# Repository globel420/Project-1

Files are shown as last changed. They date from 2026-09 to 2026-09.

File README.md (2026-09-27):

# MAKR 100 — Project 1

## Binary Counter and Logical Operators

**Harry Bartos · MAKR 100 · Fall 2026**

I combined Option A and Option B into one Arduino Uno project. The same set of LEDs displays a binary count in one mode and logical operators in the other. A short press counts; a five-second hold switches modes. The circuit is housed in a custom 3D-printed enclosure.

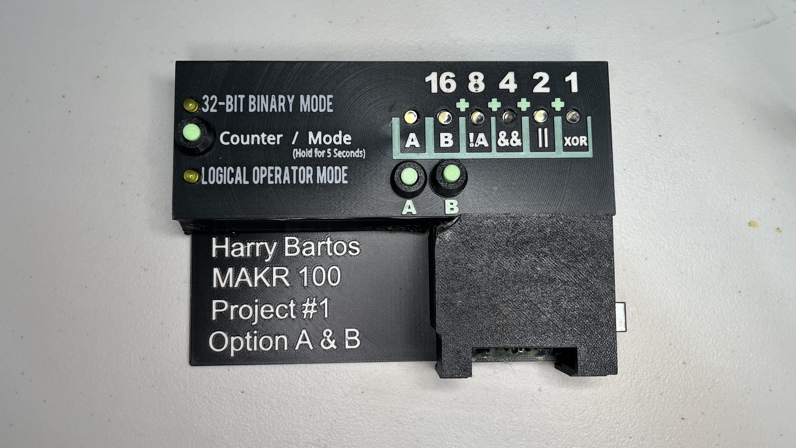
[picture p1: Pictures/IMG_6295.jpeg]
Project 1 enclosure with labeled LEDs, Counter/Mode button, and A/B buttons


## What it does

- **Project A — Binary counter:** counts from **0 to 31** using five LEDs with weights **16, 8, 4, 2, 1**. The next count after 31 returns to 0. Five bits give 32 possible values.
- **Project B — Logical operators:** buttons A and B control six outputs: **A**, **B**, **NOT A**, **AND**, **OR**, and **XOR**.
- **Shared controls:** hold Counter/Mode for five seconds to switch projects. Two indicator LEDs show the active mode. The count is preserved when switching modes and resets to zero when the Arduino restarts.
- **Serial output:** displays the decimal count or logic results at **9600 baud**.

### Controls

| Control | Action |
| --- | --- |
| Counter/Mode: short press and release | Add one in Project A; the increment happens on release |
| Counter/Mode: hold for five seconds | Switch between Projects A and B |
| Button A / Button B | Set the two inputs in Project B |

The buttons connect to ground and use `INPUT_PULLUP`: pressed reads `LOW`, released reads `HIGH`. The Mode button has a 50 ms debounce interval, and one long hold changes modes only once.

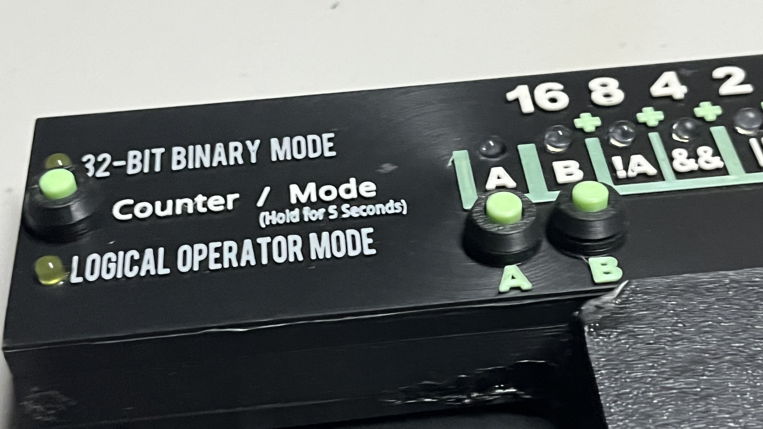
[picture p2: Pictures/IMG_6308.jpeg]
Close-up of the mode indicators, printed labels, and A/B controls


## Demo video

**Coming soon — the finished demonstration video has not been recorded yet.**

The files in [Pictures](Pictures/) and [Video](Video/) include photos, saved camera clips, animation drafts, and narration material. They are working materials for the project, not a finished demonstration video.

## Hardware and wiring

- Arduino Uno R3 and a USB cable
- Three push buttons
- Six shared data LEDs and two mode indicator LEDs
- Eight 220 Ω resistors, one for each LED
- Prototyping board, wire, and the printed enclosure

The full quantities are in [List Of Materials.xlsx](List%20Of%20Materials.xlsx).

| Uno pin | Project A: binary counter | Project B: logical operators |
| --- | --- | --- |
| D2 | Counter/Mode button | Mode button |
| D3 | Button A, unused in this mode | Button A input |
| D4 | Button B, unused in this mode | Button B input |
| D5 | Project A indicator on | Project A indicator off |
| D6 | Project B indicator off | Project B indicator on |
| D7 | Off | A |
| D8 | 16s bit | B |
| D9 | 8s bit | NOT A |
| D10 | 4s bit | A AND B |
| D11 | 2s bit | A OR B |
| D12 | 1s bit | XOR: exactly one input pressed |

### Circuit layout

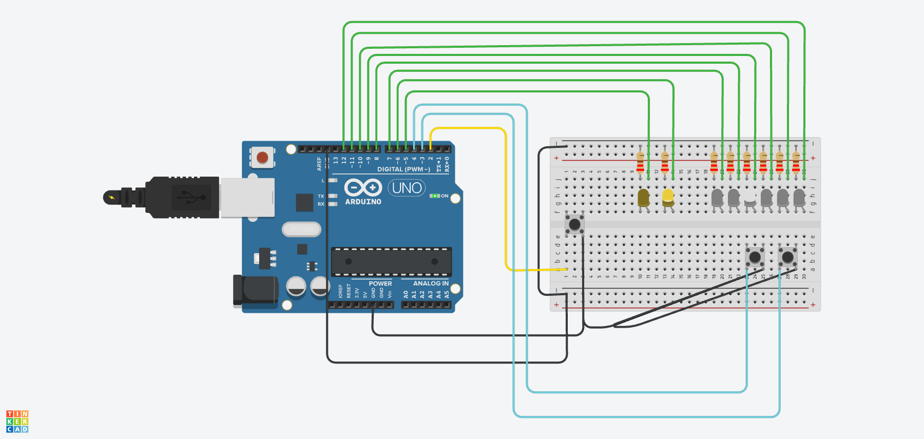
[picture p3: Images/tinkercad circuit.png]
Tinkercad circuit showing the Arduino Uno, eight LEDs with resistors, and three buttons


See the [wiring diagram PDF](Images/Wire%20Diagram.pdf) for another view. The current pin assignments and behavior are defined in [Program.cpp](Program/Program.cpp).

### Logic results

Here, **1 means pressed/on** and **0 means released/off**.

| A | B | NOT A | AND | OR | XOR |
| --- | --- | --- | --- | --- | --- |
| 0 | 0 | 1 | 0 | 0 | 0 |
| 1 | 0 | 0 | 0 | 1 | 1 |
| 0 | 1 | 1 | 0 | 1 | 1 |
| 1 | 1 | 0 | 1 | 1 | 0 |

The program uses the full XOR expression: `(A && !B) || (!A && B)`.

## Build and upload

The active source is **[Program/Program.cpp](Program/Program.cpp)**. [platformio.ini](platformio.ini) selects the Arduino Uno, the Arduino framework, and the `Program` source folder.

1. Open this repository folder in **VS Code with PlatformIO**.
2. Connect the Uno by USB.
3. Select **PlatformIO → Project Tasks → uno → General → Build**.
4. Select **Upload** to compile and write the firmware to the board.
5. Open **Monitor** at **9600 baud**.

With PlatformIO Core available in your terminal, run these commands from the repository root:

```sh
pio run -e uno
pio run -e uno --target upload
pio device monitor --baud 9600
```

The `.cpp` conversion added function declarations without changing program logic. Both versions built successfully, and the resulting firmware files were byte-for-byte identical: **3,422 bytes of flash and 409 bytes of RAM**. The original `.ino` and comparison record are preserved in [Backups](Backups/).

Keep the backup sketch outside `Program/` so PlatformIO compiles only the active source.

## Project files

| Location | Contents |
| --- | --- |
| [Program](Program/) | Main combined counter/logic program |
| [Binary_Counter_Only](Binary_Counter_Only/) | Standalone counter sketch and its flowcharts |
| [Flowcharts](Flowcharts/) | Main program, button, counter, and logic flowcharts |
| [Images](Images/) | Circuit diagram and additional flowchart images |
| [Pictures](Pictures/) | Build photos and saved camera clips |
| [print files](print%20files/) | Bambu Studio 3MF project and enclosure/button STL files |
| [Report](Report/) | Word and Markdown project report, plus inventory notes |
| [Video](Video/) | Animation sources, draft exports, scripts, and archived revisions |
| [Diagnostics](Diagnostics/) | Mode-button troubleshooting notes and diagnostic sketch |
| [Backups](Backups/) | Original sketch and conversion records |
| [Instructions.pdf](Instructions.pdf) | Assignment instructions |

The report and older diagrams may refer to `Program.ino`; the active PlatformIO source is now `Program.cpp`.

### Downloading the media

Video files are stored with **Git LFS**. To get the full media files when cloning:

```sh
git lfs install
git clone https://github.com/globel420/Project-1.git
cd Project-1
git lfs pull
```

Build output, macOS metadata, and local automation caches are excluded from Git.

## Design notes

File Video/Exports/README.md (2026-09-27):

# Project 1 animation exports

Silent 1080p animation prepared for your own spoken narration.

| Video | Length | Contents |
|---|---:|---|
| Project_1_LED_Animation.mp4 | 3:30 | Complete corrected animation |
| Binary_Counter_Animation.mp4 | 1:50 | LED values, 13, main functions, actual shift/mask operations, rollover |
| Logic_Operators_Animation.mp4 | 1:40 | Button states, NOT A, AND, OR, XOR, all combinations, repeat loop |

All three are H.264 MP4, 1920 × 1080, 24 frames per second, with no audio track.

The complete animation follows `../Animation_Spoken_Script.md` and `../Animation_Narration.srt`. The logic-only video starts at 1:50 in the full animation, so its local time begins 110 seconds earlier than the full-script timestamps.

Use the animation full frame for the explanation or place it beside your recorded hardware footage. The animation is an illustration of the sketch, not a live Arduino connection.

Mint means ON / 1. Gray means OFF / 0. Amber highlights the position or rule currently being explained; the highlight itself does not change the LED result.

## Corrected binary section

- The LED graphics run left to right as 1, 2, 4, 8, 16, following array indices 0 through 4 and pins D12 through D8.
- Written binary used in calculations retains its highest-value position on the left. It is labeled separately from the LED layout.
- The animation shows the actual Arduino bitRead operation: `(value >> bit) & 0x01`. It shifts right, masks all but the rightmost bit, then writes the 0 or 1 result to the pin.
- The comparison shows count 2 returning 1 for the 2s LED, while count 13 returns 0 for that same LED.
- The full and binary videos replace the prior explanation. The logic-only MP4 is preserved byte for byte.

QA: all scene layouts inspected; input, shifted, and masked binary values and pin mappings checked against the narration contract; all three final videos fully decoded without errors. QA_Stills includes frames extracted from the completed MP4, including the shift/mask comparison, the 2s bit, and XOR with both buttons pressed. Exact stream and duration checks are in render_validation.json.

Prior exports and superseded QA are preserved under `../render_work/archive_before_shift_mask_revision/`.

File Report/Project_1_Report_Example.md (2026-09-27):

# Project 1 Report

## Binary Counter and Logical Operators

Harry Bartos  
MAKR 100 Introduction to Microcontrollers and Physical Computing  
Instructor Nicole Shuman  
Fall 2026

### What I completed

For Project 1, I completed both Option A, the binary counter, and Option B, the logical operators project. I combined them into one Arduino build with a shared set of LEDs and a button that switches between the two modes. I also 3D printed a shell for the project and moved the circuit from the breadboard onto a soldered prototyping board.

I decided to do both because I have a passion for making things, and I had the opportunity. That was a big part of it. I know I probably won't have as many chances to do extra work like this later in the semester, so I wanted to take advantage of the time and equipment I had available. Combining the two options gave me a little more to figure out, especially because the same LEDs have different jobs depending on which project is running.

### Materials I used

My materials list records the following parts and printing material.

| Component or material | Quantity | Use |
| --- | --- | --- |
| Arduino Uno R3 | 1 | Runs both project modes |
| Push buttons | 3 | Counter/Mode button and inputs A and B |
| Data LEDs | 6 | Shared binary and logical output display |
| Yellow mode indicator LEDs | 2 | Show which project is active |
| 220 ohm resistors | 8 | One in series with each LED |
| Solderable prototyping board | 1 | Holds the soldered circuit |
| 22 gauge stranded copper wire | 40 inches | Circuit connections |
| Black PLA | 151 grams | Printed project parts |
| Green glow PLA | 34 grams | Printed project parts |
| White PLA | 4 grams | Printed project parts |

I also used a solderless breadboard during the earlier part of the build. Reproducing the project requires a suitable USB cable and a computer with the Arduino IDE to upload the sketch. The enclosure parts are saved as STL files, and the Bambu Studio project is included as a 3MF file.

### Designing in Tinkercad and printing the shell

I did the design work in Tinkercad. I used the circuit simulator to work on the electronics, and I also designed the 3D parts there. The 3D design probably took me the most time out of the whole project.

I was able to print the project's shell early on, and there is a personal reason that part of the project meant a lot to me. Falcons Care at Folsom Lake College helped me with temporary housing during the first part of the month. I was staying at Extended Stay, which gave me the chance to bring my 3D printer out of storage for the first time in about two years.

I had a great time finally being able to print again. Having the printer available meant I could make an enclosure for this assignment while I had the chance. I had missed being able to take something I was working on and turn it into a physical part.

I would have spent more time on the 3D parts if I'd had the chance, but I had to call it on September 19. It was time to pack my printer back up, and it was still hot when I packed it.

The saved print files include a body shell, top plate, bottom base, and an Arduino cover. There are also separate button parts. The top plate gives the LEDs labels for both projects, and the base includes my name and the class information. Since the LEDs change jobs between modes, those labels help explain what the display is showing.

### Building the circuit and changing plans

I used Tinkercad's simulator to work on the circuit and a breadboard for the physical build. Later in the project, I was breaking pins off in the breadboard to try to make sure the connections made contact. That turned out to be a bad plan. I was trying to get the circuit to stay connected, and the way I was doing it was creating another problem.

When I was putting things back into storage, I came across a stash of ProtoSlim prototyping boards. I decided to use one and solder the project onto it. That decision came pretty late in the project, but I was happy to finally have a use for one of those boards. And I still have four more.

The soldered version uses the same electrical connections as the breadboard design. All of the buttons connect their assigned input pin to ground when pressed. The sketch uses INPUT_PULLUP, so an unpressed button reads HIGH and a pressed button reads LOW. That means the buttons do not need separate external pull-up resistors in this design.

Each LED has its own 220 ohm resistor in series. The LED circuits return to the Arduino's ground, and the code turns an LED on by setting its output pin HIGH. To reproduce the wiring, connect each output through its resistor and LED to ground, with the LED's anode toward the output and cathode toward ground. For each push button, use contacts that become connected when the button is pressed.

### Pin connections

The following pin map matches the Program.ino file in my project folder. The six data LEDs use D7 through D12. Five of them display the counter, while all six are used in the logical operators mode.

| Arduino pin | Project A binary counter | Project B logical operators |
| --- | --- | --- |
| D2 | Counter/Mode button to ground | Mode button to ground |
| D3 | Button A, unused in this mode | Button A input to ground |
| D4 | Button B, unused in this mode | Button B input to ground |
| D5 | Project A indicator on | Project A indicator off |
| D6 | Project B indicator off | Project B indicator on |
| D7 | Data LED off | A indicator |
| D8 | 16s bit | B indicator |
| D9 | 8s bit | NOT A, !A |
| D10 | 4s bit | AND, A && B |
| D11 | 2s bit | OR, A \|\| B |
| D12 | 1s bit | Exclusive OR, (A && !B) \|\| (!A && B) |

Tinkercad circuit layout

*Figure 1. My saved Tinkercad circuit layout shows the shared LED display and three buttons. It documents the circuit connections before the move to the soldered board.*

### How the binary counter works

The program starts in Project A with the counter at zero. All five binary LEDs are off, and the separate Project A indicator is on. Each short press and release of the Counter/Mode button increases the count by one. In this version of the code, the increment happens when the button is released. That lets the same button handle counting and a longer hold for changing modes.

The binary display uses five bits, which gives it 32 possible values, from 0 through 31. From D8 through D12, the LED values are 16, 8, 4, 2, and 1. For example, 13 is 8 + 4 + 1, so the LEDs on D9, D10, and D12 turn on. Read from the 16s position to the 1s position, that is 01101.

At 31, all five binary LEDs are on. The next short press and release resets the count to zero. D7 stays off throughout counter mode because this part of the project only needs five data LEDs. The code also prints the decimal count to the Serial Monitor at 9600 baud, which gives another way to compare the number with the LED pattern.

### Switching between the two projects

Holding the Counter/Mode button for five seconds switches to the other project. The two mode indicator LEDs show which one is active. The program remembers that it has already handled a long hold, so continuing to hold the button does not keep switching back and forth. Releasing that hold also does not add an extra count.

The Mode button uses a 50 millisecond debounce interval. The program waits for a stable reading before accepting a change, which helps prevent one physical press from being counted several times. It measures the hold with millis(), allowing the main loop to keep running while it checks the elapsed time.

The counter value is preserved when changing modes. If the count is 13 when I switch to Project B, returning to Project A brings back 13. Turning the Arduino off or resetting it starts the program over at zero.

### How the logical operators work

In Project B, the two input buttons represent A and B. Their indicator LEDs show whether each button is pressed. The other four LEDs show !A, A && B, A || B, and (A && !B) || (!A && B).

The last expression is exclusive OR, often called XOR. It is true when exactly one button is pressed. I kept the full expression in the program because that is the expression requested in the assignment.

These are the expected results for every combination. Here, 1 means pressed or on, and 0 means released or off. The A and B columns also describe their indicator LEDs.

| A | B | !A | A AND B | A OR B | XOR |
| --- | --- | --- | --- | --- | --- |
| 0 | 0 | 1 | 0 | 0 | 0 |
| 1 | 0 | 0 | 0 | 1 | 1 |
| 0 | 1 | 1 | 0 | 1 | 1 |
| 1 | 1 | 0 | 1 | 1 | 0 |

When neither button is pressed, the !A LED is on. When both are pressed, the A and B indicators are on along with AND and OR. XOR is off because both inputs are true. That difference between OR and XOR is easy to see on the LEDs.

Project B updates the LEDs as the program runs. It prints a line to the Serial Monitor when entering this mode and whenever either input changes, so the monitor does not fill up with the same information over and over.

### Organizing the program

Combining the two projects meant keeping track of the LED order carefully. I used separate arrays for the binary display and the logical operators. The binary array starts with D12 as the 1s bit, while the logic array starts with D7 as the A indicator. This lets both projects use the same physical LEDs without forcing both displays into the same order.

The main loop checks the Mode button first, then runs whichever project is active. Functions handle the counter and draw its binary value. Other functions change modes or calculate the logical outputs. Keeping those jobs separate makes the sketch easier to follow. The program also clears the shared LEDs before changing displays so a light from the previous mode does not stay on with the wrong meaning.

My project folder includes flowcharts for the main loop and Mode button handling. The counter and logical operators have their own flowcharts as well. These give another way to follow the decisions in the code.

### Reproducing and demonstrating the build

Someone reproducing this project can use the following order with the pin map and circuit image above:

1. Build the button and LED circuits on a breadboard. Use a common ground and one 220 ohm resistor per LED. Wire the buttons to D2, D3, and D4 as shown.
2. Open Program/Program.ino in the Arduino IDE. Select the Uno board and the correct connected port, verify the sketch, and upload it.
3. Open the Serial Monitor at 9600 baud. Check that the program starts in Project A at zero and compare the LED pattern with the decimal count.
4. Check the full count through 31 and the next press back to zero. Hold the Mode button for five seconds, then check all four A/B input combinations against the table.
5. Switch back to Project A and check that its saved count returns. Also check that one long hold changes modes only once and that releasing it does not add a count.
6. Print the enclosure parts from the supplied STL or 3MF files. Check their fit around the actual components. After transferring the circuit to a solderable board and fitting the enclosure, repeat the same electrical checks.

My demonstration will show the counter and its reset, then the mode change and all four input combinations in Project B. The mode indicators make it clear which project is running while I explain the shared LEDs.

### Connections to my other classes

This project follows along with a lot of what I am doing in CISP 300. The program uses variables and conditions to decide what happens next, and the Boolean expressions are directly connected to the logical operators in Option B. Loops and functions also have a clear job here. I can see the result of a condition right in front of me when an LED turns on.

The move to a soldered board also connects with ET 308, Technical Soldering Practices and Techniques. I had a reason to use the soldering work from that class on something I was building for another class. The breadboard problems made that connection pretty clear. A program can describe the right behavior and still depend on the physical connections being made properly.

### AI assistance and other help

I was able to do both projects, but combining them into one build is where I relied on some AI guidance. Most of that help came through my OpenClaw server on a free Oracle Cloud Infrastructure instance. My main agents run through Hermes, with custom routing that decides which model handles a task.

For coding sessions at my Mac, my setup uses Qwen 2.5-Coder 14B running locally. My broader setup also uses NVIDIA Nemotron models through OpenRouter's free options, and I sometimes use OpenAI's API.

AI helped guide the coding needed to combine the two options. I also used OpenAI Codex to review my project files and help organize and edit this report from my own account of the build. The printing and hands-on assembly were my work, and the personal experiences described here are mine.

The assignment requirements came from Nicole Shuman's MAKR 100 Project 1 instructions for Fall 2026. I used Tinkercad to design and simulate the circuit, and I also designed the 3D parts there. The saved 3MF file contains the Bambu Studio print project. The report's pin assignments and program behavior come from Program/Program.ino, and the quantities come from List Of Materials.xlsx. Falcons Care at Folsom Lake College provided the housing support that made it possible for me to get my printer out and use it during this project.

### What I would do differently

If I built this again, I would plan the soldered board layout earlier. Finding those boards late changed how I finished the circuit, and I would rather make that decision before spending time trying to keep unreliable breadboard connections working. I would also decide the shared LED positions and enclosure labels early, since the two modes use the display differently.

I am glad I did both options while I had the chance. I got to use some of what I am working on in my other classes, and I got my printer out of storage after about two years. I had missed making things with it.

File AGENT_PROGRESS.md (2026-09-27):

# Agent Progress

## Current Resume Point
- Last updated: 2026-09-26 22:42
- Active goal: Commit and push Project 1 files with README and pictures
- Current status: Complete: project content and illustrated README pushed and verified on origin/main
- Files touched: README.md, .gitignore, .gitattributes, project artifacts and media, AGENT_PROGRESS.md
- Commands run: git push origin main: success; gh API remote commit/readme checks: passed; git ls-remote: matching commit; git lfs fsck: OK
- Validation state: 206 changed files in content commit. No finished demo video claimed. Existing firmware remains byte-for-byte identical to original. Private repository visibility retained.
- Next action: Continue project work; replace demo placeholder when the user has recorded the demonstration
- Blockers: none
- Do not repeat: none recorded

## Chapter Log

### 2026-09-26 21:15 - Configure PlatformIO for existing Arduino sketch
- Goal: Set up PlatformIO in VS Code for Program/Program.ino and Arduino Uno
- Progress: PlatformIO Core 6.1.19 and atmelavr 5.3.0 are installed. Device discovery identifies Arduino Uno. Project source uses Serial.begin(9600). A separate MAKR100 template is open in the multi-root workspace.
- Decisions: none recorded
- Files changed: AGENT_PROGRESS.md
- Commands/results: pio --version; pio device list; inspected workspace settings
- Validation: USB board detected by PlatformIO; build pending
- Next: Add configuration pointing to existing Program folder, build, select correct VS Code project, and verify serial access
- Blockers: none

### 2026-09-26 21:18 - Build and USB serial verified
- Goal: Set up PlatformIO in VS Code for Program/Program.ino and Arduino Uno
- Progress: PlatformIO builds the original Program folder. Uno detected over USB. Serial monitor at 9600 baud received Project A: Binary Counter and Counter: 0. VS Code now selects Default (Project 1).
- Decisions: none recorded
- Files changed: platformio.ini, .gitignore, .vscode/c_cpp_properties.json, .vscode/extensions.json, .vscode/launch.json, AGENT_PROGRESS.md
- Commands/results: pio project init --ide vscode --environment uno: success; pio run -e uno: success; pio device monitor: connected and received expected startup lines
- Validation: 3422 bytes flash, 409 bytes RAM; serial data verified; no firmware uploaded
- Next: Open VS Code PlatformIO Serial Monitor and verify Project 1 configuration in UI
- Blockers: none

### 2026-09-26 21:19 - PlatformIO setup complete and monitor live in VS Code
- Goal: Set up PlatformIO in VS Code for Program/Program.ino and Arduino Uno
- Progress: Saved platformio.ini using Program as src_dir, Arduino Uno with atmelavr 5.3.0, and 9600 baud. Generated VS Code metadata. VS Code Monitor auto-saved an existing unsaved edit containing stray characters on Serial.println line 161; backed up that version to a temporary file and repaired only that line. Final build passed.
- Decisions: none recorded
- Files changed: platformio.ini, .gitignore, .vscode/c_cpp_properties.json, .vscode/extensions.json, .vscode/launch.json, AGENT_PROGRESS.md, restored Program/Program.ino line 161
- Commands/results: pio project init --ide vscode -e uno succeeded; final pio run -e uno succeeded; PlatformIO Serial Monitor launched through VS Code
- Validation: Final build: 3422 bytes flash, 409 bytes RAM. VS Code screenshot confirms Default (Project 1), monitor on the Uno at 9600 8-N-1, and received Project A: Binary Counter / Counter: 0. No firmware uploaded.
- Next: User may select uno > General > Upload when ready; Serial Monitor is left running in VS Code
- Blockers: No setup blockers. Existing editor diagnostics on separate Binary_Counter_Only.ino and unrelated Python extension notifications remain outside this setup.

### 2026-09-26 21:22 - Fix eleven Arduino editor diagnostics
- Goal: Resolve the eleven VS Code C/C++ problems in Binary_Counter_Only.ino
- Progress: Live Problems panel reports eleven undefined Arduino identifiers in Binary_Counter_Only.ino. PlatformIO include paths already point to the installed Uno core, but the sketch does not explicitly include Arduino.h.
- Decisions: none recorded
- Files changed: AGENT_PROGRESS.md
- Commands/results: Inspected source, generated IntelliSense configuration, and live Problems panel
- Validation: Issue reproduced in VS Code
- Next: Add Arduino.h and displayCount forward declaration, compile the affected sketch, and verify Problems count reaches zero
- Blockers: none

### 2026-09-26 21:22 - All eleven VS Code problems resolved
- Goal: Resolve the eleven VS Code C/C++ problems in Binary_Counter_Only.ino
- Progress: Added explicit Arduino.h include and displayCount forward declaration to Binary_Counter_Only.ino. No counting, pin, timing, or serial behavior changes.
- Decisions: none recorded
- Files changed: Binary_Counter_Only/Binary_Counter_Only.ino, AGENT_PROGRESS.md
- Commands/results: arduino-cli compile --fqbn arduino:avr:uno Binary_Counter_Only: exit 0
- Validation: Compile uses 2546 bytes flash and 212 bytes RAM. Live VS Code Problems panel says No problems have been detected in the workspace, with zero errors and zero warnings.
- Next: Continue editing normally; PlatformIO main environment still builds Program/Program.ino
- Blockers: none

### 2026-09-26 21:45 - Begin Arduino C++ conversion
- Goal: Convert Program.ino to Program.cpp without changing behavior
- Progress: Confirmed Arduino include and eight helper functions; PlatformIO targets Program with Arduino Uno.
- Decisions: none recorded
- Files changed: AGENT_PROGRESS.md
- Commands/results: Inspected live sketch and PlatformIO configuration
- Validation: Build pending
- Next: Back up current sketch, build baseline, add declarations, rename, rebuild and compare firmware
- Blockers: none

### 2026-09-26 21:45 - Sketch converted with original preserved
- Goal: Convert Program.ino to Program.cpp without changing behavior
- Progress: Saved exact original and baseline firmware in Backups/ino-to-cpp-20260926-214519. Added eight declarations and renamed source; all original bytes otherwise preserved.
- Decisions: none recorded
- Files changed: Program/Program.cpp, Program/Program.ino (renamed), Backups/ino-to-cpp-20260926-214519, AGENT_PROGRESS.md
- Commands/results: pio run -e uno: baseline success
- Validation: Baseline uses 3422 bytes flash and 409 bytes RAM; backup and source preservation assertions passed
- Next: Build Program.cpp and compare firmware with baseline
- Blockers: none

### 2026-09-26 21:46 - C++ conversion verified with identical firmware
- Goal: Convert Program.ino to Program.cpp without changing behavior
- Progress: Program/Program.cpp is the only active source file. Added eight forward declarations, preserving all original source bytes otherwise. Exact original and baseline firmware are in Backups/ino-to-cpp-20260926-214519; conversion.json records hashes and comparison.
- Decisions: none recorded
- Files changed: Program/Program.cpp, Program/Program.ino (renamed), Backups/ino-to-cpp-20260926-214519, AGENT_PROGRESS.md
- Commands/results: pio run -e uno passed before and after conversion; compared complete firmware.hex files and inspected source diff
- Validation: Both builds use 3422 bytes flash and 409 bytes RAM. Firmware SHA-256 matches: c8ae001c5ee4b644b3ad5c9273d19b944c3b2930bb5f49857ea8ac2115d2b32f. No upload or physical hardware test performed.
- Next: Continue editing Program/Program.cpp in PlatformIO; keep backup outside Program folder
- Blockers: none

### 2026-09-26 21:47 - Repair stale VS Code sketch editor
- Goal: Resolve remaining invalid INO warning after C++ conversion
- Progress: PlatformIO points to Program. Live editor still targets missing Program.ino and emits INO IntelliSense warning.
- Decisions: none recorded
- Files changed: AGENT_PROGRESS.md
- Commands/results: Inspected source, configuration, prior conversion checkpoint, and VS Code accessibility state
- Validation: Live stale editor reproduced; build pending
- Next: Save unsaved buffer to backup, compare with Program.cpp, open current source and verify IDE build
- Blockers: none

### 2026-09-26 21:49 - Stale Arduino tab preserved and current C++ editor verified
- Goal: Resolve remaining invalid INO warning after C++ conversion
- Progress: Saved the stale unsaved INO buffer as Backups/Program-unsaved-buffer-20260926.ino.txt and closed its tab. Opened Program/Program.cpp in the existing VS Code workspace. The preserved buffer contained the same helper declarations already in the converted source.
- Decisions: none recorded
- Files changed: Backups/Program-unsaved-buffer-20260926.ino.txt, AGENT_PROGRESS.md
- Commands/results: pio run -e uno: success; VS Code PlatformIO Build (Project 1): SUCCESS in 0.64 seconds; inspected Problems panel and final build screenshot
- Validation: VS Code reports zero errors and zero warnings. Both CLI and IDE builds use 3422 bytes flash and 409 bytes RAM. No firmware uploaded.
- Next: Edit Program/Program.cpp; use PlatformIO controls in the Project 1 environment
- Blockers: none

### 2026-09-26 21:49 - Current C++ source opened and IDE build verified
- Goal: Resolve remaining invalid INO warning after C++ conversion
- Progress: Saved old editor buffer in Backups. Differences from Program.cpp are only a comment and whitespace. VS Code recognizes active source as C++ with PlatformIO configuration.
- Decisions: none recorded
- Files changed: Backups/Program-unsaved-buffer-20260926.ino.txt, AGENT_PROGRESS.md
- Commands/results: PlatformIO Build invoked through VS Code: SUCCESS in 0.64s; compared recovered editor and firmware hash
- Validation: Live screenshot shows Program.cpp active, C++ status, zero errors and warnings, and successful Project 1 build: 3422 bytes flash and 409 bytes RAM. Firmware hash remains c8ae001c5ee4b644b3ad5c9273d19b944c3b2930bb5f49857ea8ac2115d2b32f. No firmware uploaded during this repair.
- Next: Continue editing Program/Program.cpp; use the PlatformIO Build action
- Blockers: none

### 2026-09-26 22:37 - Prepare complete GitHub update and illustrated README
- Goal: Commit and push Project 1 files with a README containing pictures and video links
- Progress: Confirmed private origin repository and main matches origin/main. Inventoried project assets; one MOV is 153 MiB. Credential-pattern scan of 49 text files found no matches.
- Decisions: none recorded
- Files changed: AGENT_PROGRESS.md
- Commands/results: git status; git fetch origin; gh repo view; project inventory and text scan
- Validation: Existing firmware build and VS Code build passed earlier; README links and staged assets pending validation
- Next: Create README, track videos with LFS, stage project artifacts, verify and push main
- Blockers: none

### 2026-09-26 22:40 - Project files and illustrated README ready to push
- Goal: Commit and push Project 1 files with README and pictures
- Progress: README includes two build photos, circuit diagram, controls, wiring and PlatformIO instructions. Finished demo is explicitly coming soon per user; existing clips and animations are working materials. Added LFS video tracking and excluded macOS metadata, local caches, generated editor files and temporary render lists. Preserved archived media and exact source backups.
- Decisions: none recorded
- Files changed: README.md, .gitignore, .gitattributes, AGENT_PROGRESS.md, project artifacts and media
- Commands/results: git add --all; staged asset and credential-pattern review; README link validation; Git blob size check; firmware comparison
- Validation: All 22 README local links exist and three referenced images are tracked. No oversized regular Git blobs; no credential-pattern matches in 56 staged text files. New README/Git configuration whitespace checks pass. Original backup/artifact whitespace preserved. Firmware remains identical to original build.
- Next: Commit main, push origin with Git LFS, verify remote commit and rendered README
- Blockers: none

### 2026-09-26 22:42 - Project 1 published to private GitHub repository
- Goal: Commit and push Project 1 files with README and pictures
- Progress: Pushed content commit 8c1bc87 to globel420/Project-1 main. Git LFS uploaded 35 unique media objects totaling 210 MB. GitHub README source matches local README and rendered HTML contains all three images plus the coming-soon demo note. Local and remote commit IDs match; worktree was clean after the content push.
- Decisions: none recorded
- Files changed: README.md, .gitignore, .gitattributes, project artifacts and media, AGENT_PROGRESS.md
- Commands/results: git push origin main: success; gh API remote commit/readme checks: passed; git ls-remote: matching commit; git lfs fsck: OK
- Validation: 206 changed files in content commit. No finished demo video claimed. Existing firmware remains byte-for-byte identical to original. Private repository visibility retained.
- Next: Continue project work; replace demo placeholder when the user has recorded the demonstration
- Blockers: none

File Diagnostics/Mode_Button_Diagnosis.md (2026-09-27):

# Mode button diagnostic result

Observed live in Arduino IDE on the connected Uno, 2026-09-26.

## Findings
- The active Downloads/Program/Program.ino matched the user-pasted source byte for byte before diagnostics.
- Original logic passed host simulation with separate press/hold/release sequences.
- Physical short presses and releases worked in Project A.
- After a physical hold entered Project B, D2 remained LOW with the button released: raw=0, stable=0, handled=1, no raw edges, increasing hold age.
- Reconnecting USB restarted Project A and restored released readings. This was a USB reconnect, not a D2 wire disconnect.
- Diagnostic serial command B entered logic mode without requiring a physical button press; D2 went LOW. Five seconds later, the original hold logic returned to A and D2 went HIGH.
- The output-isolation probe inverted each LED output individually, sampled D2, and restored the output before testing the next pin.

## Output-isolation result
```text
DBG probe D5 out=1->0 D2=1->0->1
DBG probe D6 out=0->1 D2=1->1->1
DBG probe D7 out=0->1 D2=1->1->1
DBG probe D8 out=0->1 D2=1->1->1
DBG probe D9 out=0->1 D2=1->1->1
DBG probe D10 out=0->1 D2=1->1->1
DBG probe D11 out=0->1 D2=1->1->1
DBG probe D12 out=0->1 D2=1->1->1
```

## Conclusion and remaining boundary
Changing D5 (Project A indicator) changes D2 (mode input), even without changing the active project or pressing the button. Thus D5 LOW in Project B prevents a released reading and prevents a new long hold from being recognized. This isolates the interacting output/input pair, but not the exact physical connection or component fault. Inspect D2 mode-button and D5 indicator wiring, return paths, and solder joints before assigning a specific defective part. No physical wiring repair is established.

## Diagnostic firmware used
The separately saved Mode_Button_Debug/Mode_Button_Debug.ino V3 diagnostic was uploaded for testing. Original project sketches were not modified. The diagnostic retains original button/mode logic and adds telemetry plus serial commands a (force A), b (force B), t (briefly probe D5-D12 and restore outputs). It compiled for arduino:avr:uno: 4414 bytes flash, 643 bytes SRAM. Use the t probe only with buttons untouched. Restore original firmware after resolving the physical cause, then verify short counts and repeated A/B/A holds on hardware.

## Original firmware restored
The user reported fixing the physical issue and requested restoration. Uploaded unchanged Downloads/Program/Program.ino through Arduino IDE to the Uno on 2026-09-26. Source still matches the pasted original (SHA256 cf77b2b2ef980e6bf59ac4a591e3912b2ba5529535c00b0e9a12d54486fc80b0). IDE reported Done uploading; Serial Monitor showed Project A: Binary Counter and Counter: 0. Diagnostic window closed; original sketch and Serial Monitor remain open. Post-repair A-to-B-to-A physical test is pending; exact physical repair was not described.

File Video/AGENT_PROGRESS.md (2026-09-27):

# Agent Progress

## Current Resume Point
- Last updated: 2026-09-26 20:25
- Active goal: Replace confusing parity explanation with the actual Arduino shift-and-mask operation, using LED array order
- Current status: Narration and webpage corrected; animation agent regenerating binary scenes and MP4s
- Files touched: animation_narration.json, Animation_Spoken_Script.md, Animation_Spoken_Script.txt, Animation_Narration.srt, Video_Script.md, index.html, concepts.js, concepts.css, AGENT_PROGRESS.md
- Commands run: Read installed Arduino macro and core version; verified every binary-bit operand, mask result, pin and weight; preserved exact 210-second timeline
- Validation state: Script, operator values, and order pass. Corrected movie encoding and visual QA are pending with render_animation agent. No Arduino source changes.
- Next action: Inspect corrected comparison and LED-order frames, verify new exports, and deliver refreshed video/script
- Blockers: None
- Do not repeat: none recorded

## Chapter Log

### 2026-09-26 19:50 - Rebuild explanation around visible decisions
- Goal: Make the LED calculation webpage intuitive for the user
- Progress: User explicitly rejected the current explanation. Binary will show target, remaining amount, and each needed place value. Logic will use two clickable inputs and one selected result. Original page preserved in Archive/led-explainer-before-redesign.
- Decisions: none recorded
- Files changed: index.html, concepts.css, concepts.js, Archive/led-explainer-before-redesign/
- Commands/results: Inspected existing webpage and reviewed current user preferences; preserved files before rewrite
- Validation: Rewrite pending; mathematical outcomes will be checked for all counts 0-31 and all logical input combinations
- Next: Implement page, verify calculations and controls, visually review desktop and narrow layout, and refresh the live preview
- Blockers: None

### 2026-09-26 20:06 - Actual code examples and binary-only sketch ready
- Goal: Show the actual main Arduino code with concrete values and provide a separate binary-only sketch
- Progress: User clarified that a code example, not a math-only visualization, is required. Replaced subtraction steps with bitRead, LED_PINS, and digitalWrite substitutions. Code and LEDs remain visible together. Created separate Binary_Counter_Only sketch with D2 button, D12-D8 LEDs, count 0-31, release debounce, and Serial output at 9600.
- Decisions: none recorded
- Files changed: index.html, concepts.js, concepts.css, led-model.js, QA/code-example.png, ../Binary_Counter_Only/Binary_Counter_Only.ino, AGENT_PROGRESS.md
- Commands/results: Arduino CLI compile arduino:avr:uno passed: 2546 bytes program and 212 bytes globals. Node checked all 32 patterns and pin mappings. Browser stepped through all 16 stages for 13 and confirmed AND and XOR for both pressed. Saved screenshot and retained live tab.
- Validation: PASS: compilation and software examples. Actual hardware upload/test not performed. Browser keyboard actions work; pointer automation did not advance controls, so native pointer interaction remains unverified.
- Next: User can review the actual code example and open the separate sketch; upload only if requested
- Blockers: None for the requested code example and separate sketch

### 2026-09-26 20:25 - Correct explanation to actual bitRead operations and LED order
- Goal: Replace confusing parity explanation with the actual Arduino shift-and-mask operation, using LED array order
- Progress: Verified installed Arduino AVR 1.8.8 Arduino.h line111 defines bitRead as a right shift followed by bitwise AND with 0x01. User clarified LED diagram must follow 1,2,4,8,16 left to right. Written binary operands remain explicitly labeled MSB-first. Added direct count2 versus13 comparison at bit1.
- Decisions: none recorded
- Files changed: animation_narration.json, Animation_Spoken_Script.md, Animation_Spoken_Script.txt, Animation_Narration.srt, Video_Script.md, index.html, concepts.js, concepts.css, AGENT_PROGRESS.md
- Commands/results: Read installed Arduino macro and core version; verified every binary-bit operand, mask result, pin and weight; preserved exact 210-second timeline
- Validation: Script, operator values, and order pass. Corrected movie encoding and visual QA are pending with render_animation agent. No Arduino source changes.
- Next: Inspect corrected comparison and LED-order frames, verify new exports, and deliver refreshed video/script
- Blockers: None

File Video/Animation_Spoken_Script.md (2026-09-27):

# Spoken script for the LED animation

Harry Bartos · MAKR 100 Project 1

**Length:** 3 minutes 30 seconds. The video is silent for your own narration. Read the paragraphs; headings and timecodes are cues.

The **1s LED is at the far right**. Across the screen from left to right, the values are **16, 8, 4, 2, 1**. The code visits the lights from right to left: bit 0 through bit 4.

The calculations follow the actual right-shift and bitwise-AND operations in Arduino’s `bitRead()` definition. Keep the overall recording order: assembled build, demonstration, construction/teardown, then explanation.

## 0:00–0:08 · How the LEDs know what to show

Here's how the Arduino decides which LEDs to turn on in each mode.

## 0:08–0:20 · Each position is worth twice as much

The ones LED is on the far right. Moving left, the values are two, four, eight, and sixteen. The code starts at the rightmost LED.

## 0:20–0:33 · Displaying thirteen

To display thirteen, the one, four, and eight lights are on. One plus four plus eight equals thirteen. The two and sixteen lights stay off.

## 0:33–0:46 · The main functions

Each short press and release calls incrementCounter, which adds one. Then showBinary reads the five bits of that number and updates the lights.

## 0:46–0:59 · The actual code inside bitRead

bitRead shifts the number right, then uses bitwise AND with one. The shift moves the chosen bit to the rightmost position. AND keeps only that bit.

## 0:59–1:07 · Bit 0: the rightmost ones LED

Shifting thirteen by zero leaves its bits unchanged. AND with one returns one, so pin twelve turns on.

## 1:07–1:15 · Bit 1: the twos LED

Thirteen shifted right once ends in zero. AND with one gives zero, so the twos LED is off.

## 1:15–1:23 · Bit 2: the fours LED

Shift thirteen right twice. The last bit is one. AND with one keeps it, turning on the fours LED.

## 1:23–1:31 · Bit 3: the eights LED

Shift thirteen right three times. The result is one. AND with one keeps it, turning on the eights LED.

## 1:31–1:39 · Bit 4: the leftmost sixteens LED

Shift thirteen right four times. The result is zero. AND with one keeps zero, so the sixteens LED stays off.

## 1:39–1:50 · Returning to zero

The one, four, and eight LEDs are on for thirteen. At thirty-one, all five are on. Another press resets the count to zero.

## 1:50–2:02 · Pressed = true     Released = false

Logical operators work with true-or-false answers. runProjectB reads the two buttons. A pressed button becomes true; a released button becomes false.

## 2:02–2:13 · Is A released?

NOT A asks, is A released? With A released, NOT A is true and its LED is on. Pressing A makes it false.

## 2:13–2:24 · Are both buttons pressed?

AND asks, are both buttons pressed? Its LED turns on only when A and B are both true.

## 2:24–2:35 · Is at least one button pressed?

OR asks, is at least one button pressed? A alone, B alone, or both together make OR true.

## 2:35–2:48 · Is exactly one button pressed?

Exclusive OR asks, is exactly one button pressed? A alone or B alone makes it true. Press both, and exclusive OR turns off.

## 2:48–2:55 · Neither button pressed

With neither button pressed, the only output light on is NOT A.

## 2:55–3:02 · A only

With A alone, the A indicator, OR, and exclusive OR are on.

## 3:02–3:09 · B only

With B alone, B, NOT A, OR, and exclusive OR are on.

## 3:09–3:18 · Both buttons pressed

With both pressed, A, B, AND, and OR are on. Exclusive OR is off.

## 3:18–3:30 · True → LED on     False → LED off

For every result, digitalWrite turns the matching LED on for true and off for false. The main loop repeats, so the display responds whenever the buttons change.

---

Verified source: Arduino AVR Boards 1.8.8, `cores/arduino/Arduino.h`, line 111:

```cpp
#define bitRead(value, bit) (((value) >> (bit)) & 0x01)
```

`>>` shifts right. `&` is bitwise AND. `0x01` is one written in hexadecimal. Binary operands show the lowest five bits because this counter ranges from 0 to 31.

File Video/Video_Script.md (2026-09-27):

# Project 1 video script

Harry Bartos · MAKR 100 · Binary Counter and Logical Operators

## Recording order

Start with the project completely assembled and covered. Demonstrate that both modes work before opening anything. Then show the construction. Finish with a slowed explanation of the program, using the earlier button-press footage beside the animated flowchart and highlighted code.

The assignment requires a video showing the project requirements in action but does not specify its duration. The separate in-class presentation is 5–7 minutes. This version focuses on the working build and the two main ideas. Allow roughly 5–7 minutes, depending on the length of the demonstration and teardown.

The words below are narration. Bracketed directions are actions to film, not words to read aloud. The described LED results are the expected results of the saved sketch; match the narration to what the hardware actually shows.

## 1. The finished build

**Picture:** Full frame. Keep the enclosure completely assembled. Start with a steady close-up, then turn it slowly to show the top, controls, sides, and base. Leave the insides covered.

**Say:**

“This is my Project 1 for MAKR 100. I combined the binary counter and the logical operators into one Arduino build. They share the same output LEDs, and this button switches between the two modes.

“I designed and printed the enclosure, including the labeled top plate and the button parts. Before I open it up, I'll show it working.”

## 2. Demonstrate the enclosed binary counter

**Picture:** Close enough to read the labels and see your finger release the button. Keep the two mode indicators visible. Start or reset the Arduino on camera. Record the count continuously from 0 through 31 and back to 0. You can pause your narration while counting, but keep the demonstration legible.

**Say:**

“It starts in Project A at zero. The Project A indicator is on, but all five counting LEDs are off.

“Each short press and release adds one. Here's one, two, and three. The light represents a one, and an unlit position represents a zero.

“These five positions are worth one, two, four, eight, and sixteen. Together they represent thirty-two different values, from zero through thirty-one.”

**[Continue to 13 and hold the shot.]**

“At thirteen, the eight, four, and one positions are on. Eight plus four plus one gives us thirteen.”

**[Continue to 31. Pause with all five counting LEDs on. Press and release once more.]**

“At thirty-one, all five are on. One more press takes it back to zero.”

**[Advance to 13 again. Keep that count for the mode-switch demonstration.]**

## 3. Demonstrate enclosed logic mode

**Picture:** Keep the enclosure closed. Hold the Counter/Mode button continuously for five seconds. Show the indicator change. Then demonstrate each A/B combination long enough to see the result. Release both buttons between combinations.

**Say:**

“I'm leaving the count at thirteen. Holding this button for five seconds switches to Project B. The mode indicator changes, and the same LEDs now show the logical results.

“These two buttons are A and B. Their indicators show whether each button is pressed. The remaining lights show NOT A, AND, OR, and exclusive OR.”

**[Neither button pressed.]**

“With neither button pressed, only NOT A is on.”

**[Press A only.]**

“With A alone, A, OR, and exclusive OR are on.”

**[Release A, then press B only.]**

“With B alone, B, NOT A, OR, and exclusive OR are on.”

**[Press both.]**

“With both pressed, A, B, AND, and OR are on. Exclusive OR turns off because it requires exactly one input.”

**[Release both, then hold Mode for five seconds.]**

“Holding Mode again brings back Project A. It also brings back thirteen. Switching modes preserves the count.”

## 4. Open it and show the construction

**Picture:** Disconnect USB power before opening the enclosure. Show the removed cover and how the pieces fit. Get separate close-ups of the Arduino, top and underside of the soldered board, buttons, resistors, wiring, and printed parts. Do not try to hold every piece while narrating; voice-over works well here.

**Say:**

“Now that you've seen it working, here's what's inside.

“The Arduino Uno runs both modes. I used three momentary buttons, six shared output LEDs, and two mode indicators. Each LED has its own resistor.

“I started with the circuit in Tinkercad and on a breadboard. After having trouble with the breadboard connections, I moved it onto a soldered prototyping board. I could also route connections underneath to keep the top cleaner.

“I designed the printed parts in Tinkercad too. The enclosure and labels bring the two projects together, even though the same LEDs have different jobs in each mode.”

For the exported animation, use **[Animation_Spoken_Script.md](Animation_Spoken_Script.md)**. It contains the exact narration matched to the 3:30 movie. The paragraphs below remain a shorter alternative for your overall project video.

## 5. How the binary counter chooses its lights

**Picture:** Show the enclosed hardware at 13 alongside the simplified **Binary numbers** illustration. The 1s LED is at the far right. Across the screen, the positions are 16, 8, 4, 2, 1. The loop starts at the rightmost LED and moves left. Keep the Serial Monitor visible briefly so the decimal count can be compared with the lights. Use **Read the five bits slowly** to point at each position without changing the diagram.

**Say:**

“Each light represents a different value: one, two, four, eight, and sixteen. The value doubles at every position because binary is base two.

“To display a number, the lights that are on must add up to that number. Thirteen is eight plus four plus one. So those three lights turn on, while sixteen and two stay off. Written in the usual sixteen-to-one binary order, that's zero, one, one, zero, one.

“The count is already stored in the Arduino as binary. incrementCounter adds one to it. showBinary takes that number and goes through the five LED positions in a loop.

“At each position, bitRead gets either a zero or a one. digitalWrite uses that result to turn the matching light off or on. So the Arduino isn't guessing a pattern. It's displaying the five bits of the number.

“At thirty-one, all five positions are one. Add another count, and the program resets it to zero.”

**Close-up of the actual code:** Show `bitRead(counter, i)`, then its Arduino definition: `(counter >> i) & 1`.

“Arduino shifts the number right by the bit position, then uses bitwise AND with one. That keeps only the bit at the far right.

“For the twos LED, i is one. Thirteen is zero-one-one-zero-one in binary. Shift right once and the result ends in zero. AND with one gives zero, so that LED is off.

“Two is zero-zero-zero-one-zero. Shift right once and the result ends in one. AND with one gives one, so the same twos LED is on.”

## 6. How the logical operators choose their lights

**Picture:** Switch to **Logical operators**. Match the illustrated A and B buttons to the real buttons in each clip. Use **Explain the four results slowly** or **Next result**. Keep the same four rules visible throughout.

**Say:**

“Logic mode uses a different rule. Each button becomes a true-or-false value. A pressed button means true, and a released button means false.

“runProjectB reads A and B, then asks four questions.

“NOT A asks whether A is released. AND asks whether both buttons are pressed. OR asks whether at least one button is pressed. Exclusive OR asks whether exactly one button is pressed.

“Every true answer turns its output light on. Every false answer turns it off.

“With A alone, OR and exclusive OR are true, but NOT A and AND are false. With both buttons pressed, AND and OR are true, but exclusive OR is false because it needs exactly one.

“The two input indicators show A and B directly. The other four lights show the answers to those questions. The program checks again as the main loop repeats, so the lights respond when I change the buttons.”

## 7. Close on the assembled project

**Picture:** End with the working project fully assembled. Reuse the opening shot or film another after reassembly.

**Say:**

“That's how the two modes use the same LEDs. One displays the bits of a number. The other displays the results of four logical conditions.”

**End credit:** “Circuit and enclosure designed in Tinkercad. AI assistance with combining the program modes and preparing this explanation; details in the project report.”

## Editing and recording notes

You can record the physical build directly into QuickTime with your iPhone as a Continuity Camera: close iPhone Mirroring, aim and lock the phone, then choose **QuickTime Player → File → New Movie Recording** and select your iPhone camera from the recording-device menu. iPhone Mirroring itself does not provide camera access. [Apple: Continuity Camera](https://support.apple.com/en-us/102546) · [QuickTime recording](https://support.apple.com/en-mk/guide/quicktime-player/qtp356b55534/mac)

- Keep the original order: fully assembled build, working demonstration of both modes, then disconnect power and open the enclosure to show its construction.
- The main explanation now focuses on the binary values and the four logic rules. Startup, debounce, pin numbers, Serial formatting, and nested function calls do not need a separate walkthrough.
- Show hardware and the simple illustration beside one another. The diagram stays in place; only the current bit or logical result gets highlighted.
- The illustration is controlled separately from the board. Match its displayed number or A/B state to the actual footage when editing.
- In Arduino IDE, the Serial Monitor shows the decimal counter and logical results. Use **Tools → Serial Monitor** or **Command-Shift-M**, with **9600 baud**. It can appear briefly beside the physical LEDs as another way to show the result.
- Use **Next light** and **Next result** to match your narration, or use the slow-play buttons. The code example uses the actual right-shift and bitwise-AND operations.
- The detailed code page remains available as a reference; it is not needed for this simpler video explanation.

## Sources used

- `../Instructions.pdf`: required behavior, video submission instructions, presentation timing, and assistance-credit requirement.
- `../Program/Program.ino`: pin map, actual functions and line numbers, debounce, release counting, mode changes, output loops, logical expressions, and Serial output.
- `../Report/Project_1_Report_Example.docx`: construction account, Tinkercad work, printed enclosure, move from breadboard to soldered board, and underside wiring.

The animation includes a snapshot of the current sketch in `source.js`. If the sketch changes later, refresh that snapshot and the line references before using it for another recording.

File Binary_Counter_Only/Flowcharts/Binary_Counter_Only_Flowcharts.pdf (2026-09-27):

MAKR 100 / PROJECT 1 / HARRY BARTOS

# Binary counter: main program

One completed press and release adds 1. The counter cycles from 0 to 31.

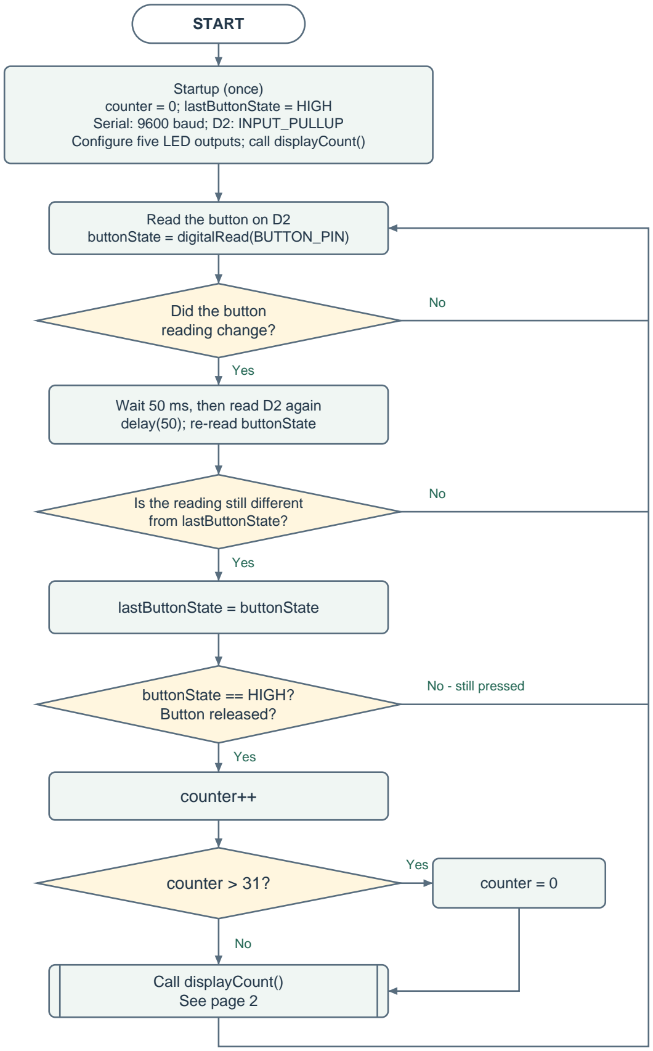
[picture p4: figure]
START; Startup (once) counter = 0; lastButtonState = HIGH Serial: 9600 baud; D2: INPUT_PULLUP; Read the button on D2 buttonState = digitalRead(BUTTON_PIN); Did the button reading change?; Wait 50 ms, then read D2 again delay(50); re-read buttonState; Is the reading still different from lastButtonState?; lastButtonState = buttonState; buttonState == HIGH? Button released?; counter++; counter > 31?; counter = 0; Call displayCount() See page 2; Yes; No - still pressed

Source: Binary_Counter_Only.ino | 1 / 2

Configure five LED outputs; call displayCount()

Return to the next loop() pass

MAKR 100 / PROJECT 1 / HARRY BARTOS

# displayCount(): choose each LED

Called once at startup, then after each increment or reset.

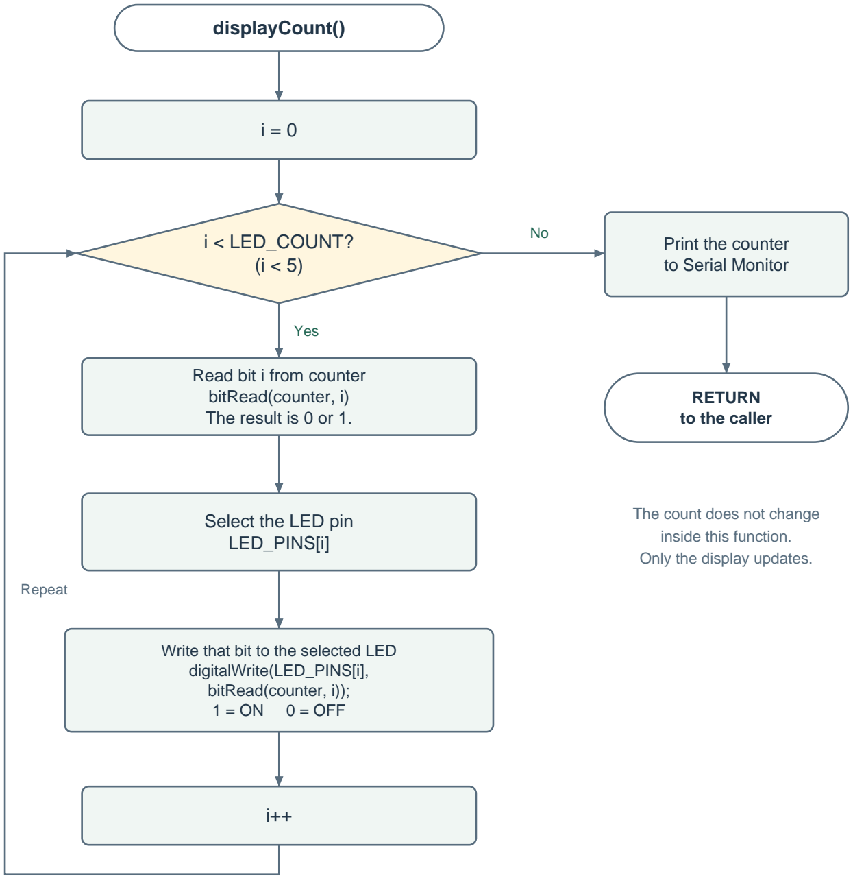
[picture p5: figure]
displayCount(); i < LED_COUNT? (i < 5); Read bit i from counter bitRead(counter, i) The result is 0 or 1.; Select the LED pin LED_PINS[i]; Write that bit to the selected LED digitalWrite(LED_PINS[i], bitRead(counter, i));; 0 = OFF; Print the counter to Serial Monitor; RETURN to the caller; Yes; Repeat; The count does not change inside this function. Only the display updates.

Source: Binary_Counter_Only.ino | 2 / 2

Each loop iteration uses the same position in the LED array.

i (bit index) | 0 | 1 | 2 | 3 | 4
LED pin | D12 | D11 | D10 | D9 | D8
Position value | 1 | 2 | 4 | 8 | 16

Example: counter = 13 lights the 8, 4, and 1 positions (01101).

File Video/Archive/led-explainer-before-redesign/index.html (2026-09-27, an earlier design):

MAKR 100 · PROJECT 1

# How the LEDs work

## Each light has a value.

Add the values of the lights that are on. That is the number.

−Number +Show 13

showBinary() uses bitRead() to read each position. A 1 turns its light on; a 0 turns it off.

Read the five bits slowlyNext light

13 uses the 8, 4, and 1 lights: 01101 in binary.

The math behind reading a bit

For a positive LED value, divide the count by that value and drop the decimal part. An odd result means 1; an even result means 0. This is the arithmetic equivalent of selecting that bit.

incrementCounter() adds one after a short press and release. After 31, it returns to 0.

## Each light answers a question.

Pressed means true. Released means false. A true result turns its light on.

A: releasedB: released

Click A or B to show that button pressed or released.

Explain the four results slowlyNext result

Neither button is pressed, so only NOT A is on.

runProjectB() reads A and B, checks these four conditions, and sends each result to its LED with digitalWrite().

This is an illustration; control it separately from your Arduino. Video script · Detailed code view

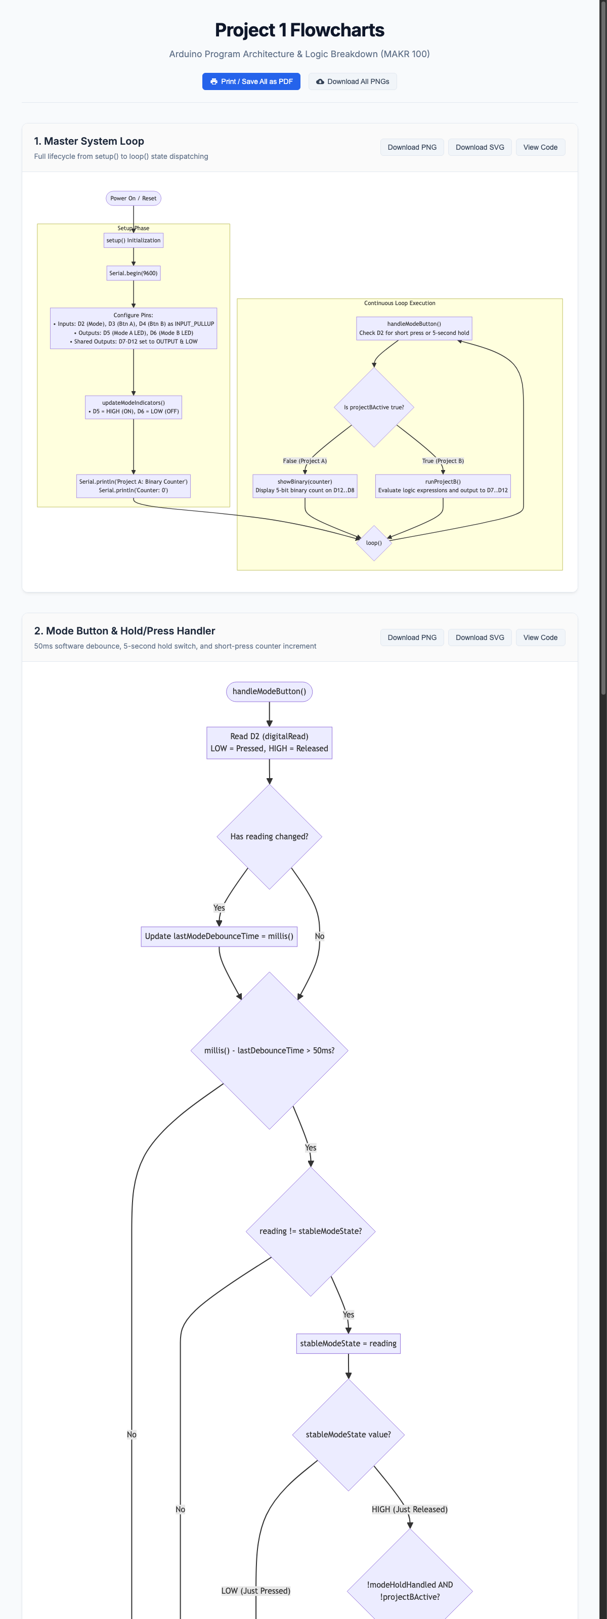
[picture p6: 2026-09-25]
Images/All_Flowcharts_Overview.png

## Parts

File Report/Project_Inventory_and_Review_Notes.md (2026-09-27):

# Project inventory and report review notes

Prepared September 25, 2026. These are preparation notes for Harry, separate from the example report.

## What the assignment asks for

Instructions.pdf requires a report with your name, a bill of materials, a description detailed enough to reproduce the project, and challenges or takeaways. There is no word limit. All sources of help, including AI, must be credited.

The submission also needs the Tinkercad circuit image, a video demonstration, and the Arduino sketch. The ZIP naming pattern is YourLastName_Project_1.zip, so yours would be Bartos_Project_1.zip. The listed deadline and in-class presentation are September 29, 2026, at 5:00 PM. The presentation should take about 5-7 minutes. The report is longer than a presentation script; use selected points for the talk.

## Source inventory

The project contained 25 non-hidden source files before the Report folder was added. Hidden metadata and Git internals are excluded.

| Location | Files | How they informed the report |
| --- | --- | --- |
| Project root | Instructions.pdf | Required report contents, citations, submission items, and presentation expectations |
| Project root | List Of Materials.xlsx | Arduino and component counts, wire quantity, filament amounts |
| Project root | flowcharts.html | Supporting explanation of program decisions and pin assignments |
| Program | Program.ino | Primary source for current pin map, debounce, mode switching, binary display, logical expressions, and serial output |
| Flowcharts | Program_Flowcharts.pdf; Program_Main_Flowchart.png; Program_Mode_Button.png; Program_Binary_Counter.png; Program_Logic_Operators.png | Four-page program documentation matching the current sketch |
| Images | tinkercad circuit.png; Wire Diagram.pdf | Circuit layout, connections, resistor values, and button wiring |
| Images | Flowcharts.pdf; All_Flowcharts_Overview.png; Flowchart_1_Master_Loop.png; Flowchart_2_Mode_Button.png; Flowchart_3_Project_A_Binary.png; Flowchart_4_Project_B_Logic.png | Additional versions of the flowchart documentation |
| print files | MAKR 100 - Project 1.3mf | Saved Bambu Studio project and five plate previews, including the base labeled Harry Bartos |
| print files/STL Files | Body shell.stl.stl; Top Plate.stl.stl; Bottom Base.stl.stl; Arduriono Cover.stl.stl; button.stl_1.stl; button.stl_2.stl; button.stl_3.stl | Enclosure and button components |

The report follows the current Program/Program.ino in this folder. No Arduino source files were changed or compiled during report preparation. The saved files establish the design and documented behavior; the printing, soldering, housing support, and AI setup are based on your account. Your follow-up confirms that you used Tinkercad for the circuit simulation and designed the 3D parts there, spent the most time on the 3D design, and had to stop on September 19 to pack the printer while it was still hot.

## Items to check before using the example as your final report

1. **Demonstration and test results.** No video file was found among the 25 source files. The report describes expected behavior and proposed demonstration steps without inventing a record of completed hardware tests. Add the actual results of your checks, including counting through 31 back to 0, all four A/B states, and switching modes while preserving the count. Include the video in the submission ZIP, or put its public YouTube link in the report as the assignment allows.
2. **Your name in the sketch.** Your name appears on the saved printed-base preview and is included in the report. I did not find Harry, Bartos, or an author/name credit in Program/Program.ino. The instructions also require your name in the sketch.
3. **Five bits and 32 values.** The code's opening comment says "0 to 31 or 32 Bits," and the top-plate preview says "32-BIT BINARY MODE." The implemented display is five bits with 32 possible values. The example report uses the correct description. A clearer label would be "5-BIT BINARY COUNTER" or "BINARY COUNTER 0-31." The source and print files were not edited.
4. **Board name and LED colors.** Your message calls the board ProtoSlim; the materials spreadsheet calls it ProtoSim Protoboard. The report uses your wording in the story and a generic solderable prototyping board in the materials table. The spreadsheet lists six white data LEDs, while the wiring PDF labels one of them blue. Check the final hardware and make the submission consistent.
5. **Help and design credits.** The example credits your AI workflow and Codex assistance with this report. Add any other people or sources that helped. The report now explicitly credits your 3D design work in Tinkercad. Keep the AI model names aligned with what you actually used.

## Files created for this request

- Project_1_Report_Example.docx: editable report with materials, pin map, truth table, and the saved circuit image.
- Project_1_Report_Example.md: the same report in editable plain text with Markdown formatting.
- Project_Inventory_and_Review_Notes.md: this inventory and the remaining factual checks.

Original source files were left unchanged. Nothing was submitted or published.

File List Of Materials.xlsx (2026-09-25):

Label | Qty | Component
U1 | 1 | Arduino Uno R3
SButton A, SMode, SButton B | 3 | Pushbutton
DLED 1 - DLED 6 | 6 | White LED
DMode A, DMode B | 2 | Yellow LED
R6, R5, R4, R3, R2, R8, R1, R7 | 8 | 220 Ω Resistor
Breadboard | 1 | ProtoSim Protoboard
Bottom - Top Shell - Arduino Shel l - Button Covers | 151 | Grams Black PLA
 | 34 | Grams Green Glow PLA
 | 4 | Grams White PLA
Project wire | 40 | Inches 22 Gauge Stranded Copper Wire
[

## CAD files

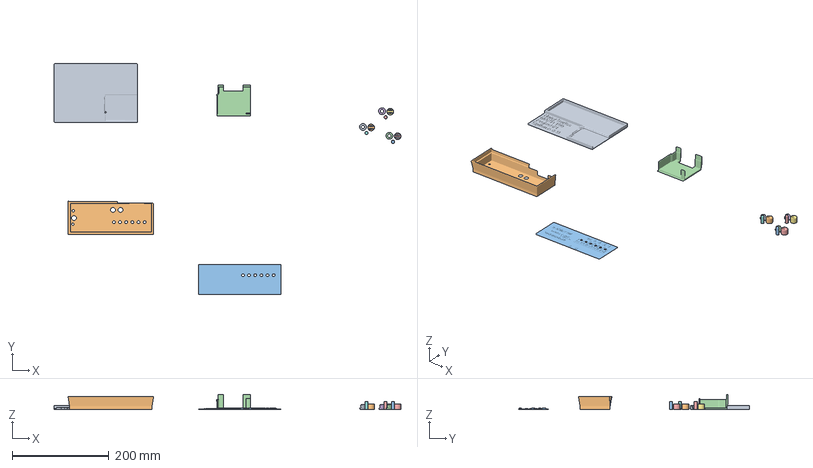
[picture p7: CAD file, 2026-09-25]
print files/MAKR 100 - Project 1.3mf
715.9 x 475.9 x 31.0 mm
Bottom Base.stl
Body shell.stl
Top Plate.stl
Arduino Cover.stl
button.stl_1 x 3
button.stl_2 x 3
button.stl_3 x 3

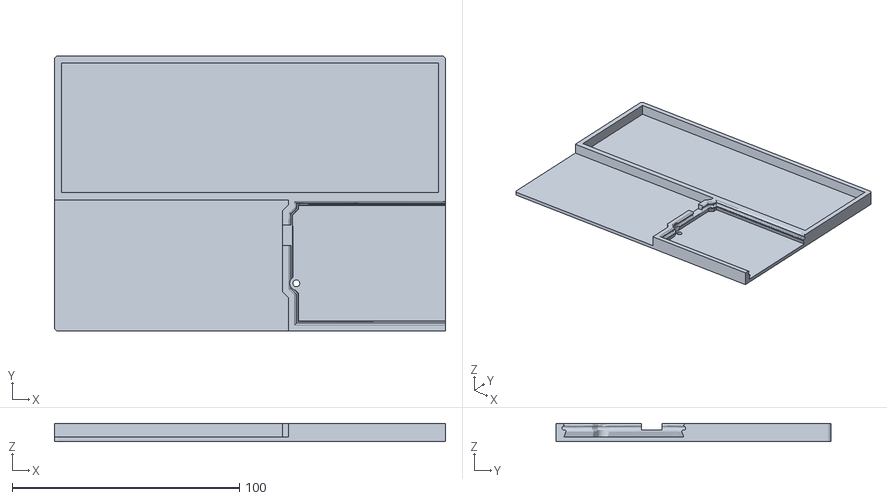
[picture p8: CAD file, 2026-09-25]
print files/STL Files/Bottom Base.stl.stl
172.0 x 121.0 x 7.99

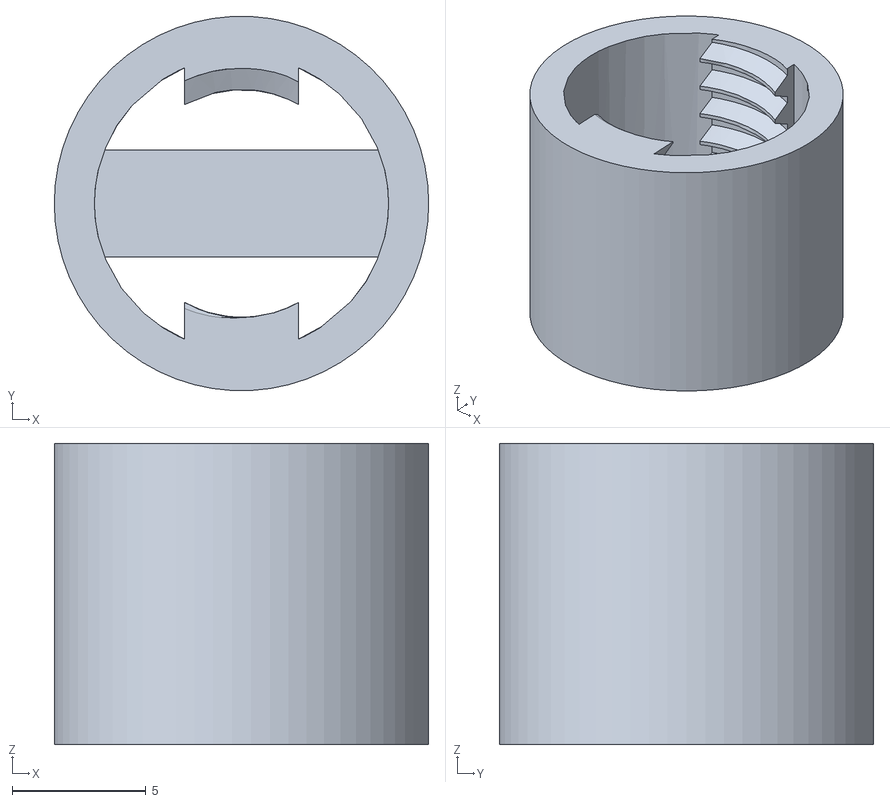
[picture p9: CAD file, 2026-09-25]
print files/STL Files/button.stl_3.stl
14.0 x 14.0 x 11.3

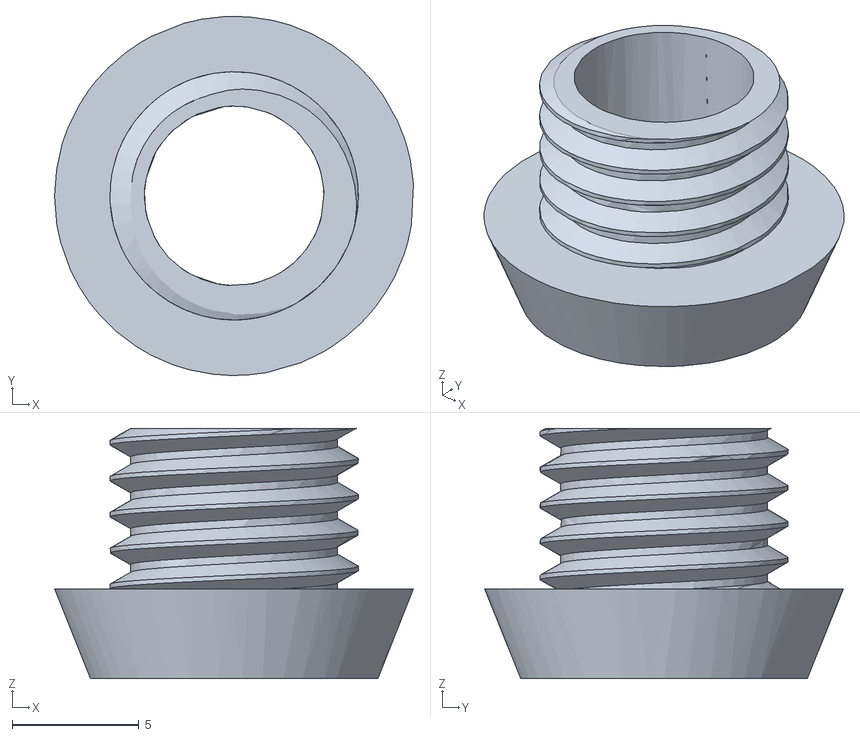
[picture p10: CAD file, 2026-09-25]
print files/STL Files/button.stl_2.stl
14.2 x 14.2 x 9.89

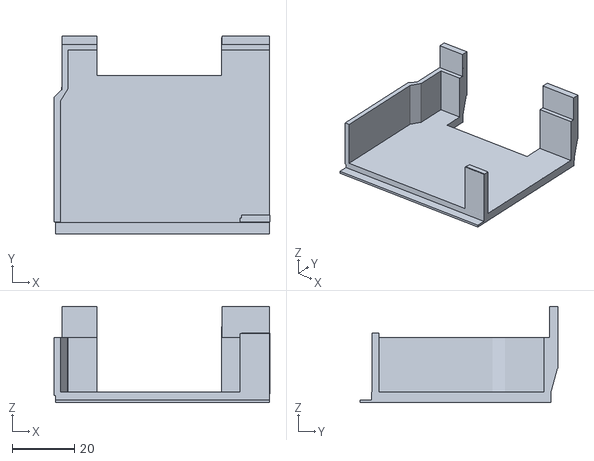
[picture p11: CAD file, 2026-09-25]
print files/STL Files/Arduriono Cover.stl.stl
69.7 x 64.0 x 31.0

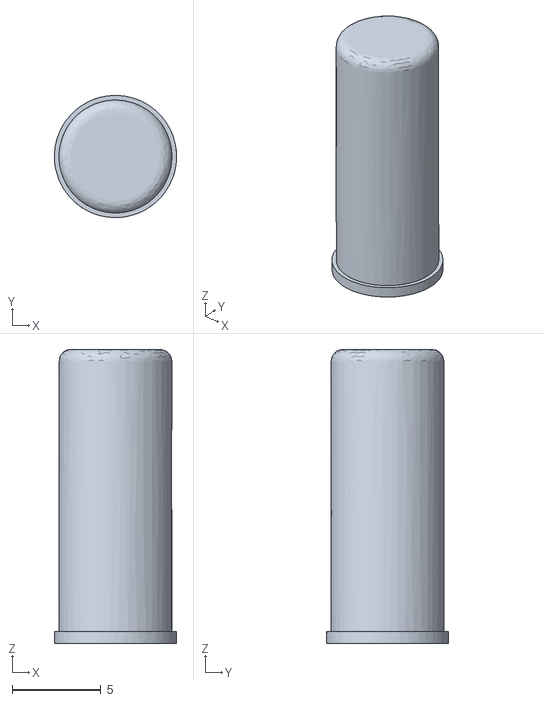
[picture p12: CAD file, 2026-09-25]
print files/STL Files/button.stl_1.stl
6.90 x 6.90 x 16.6

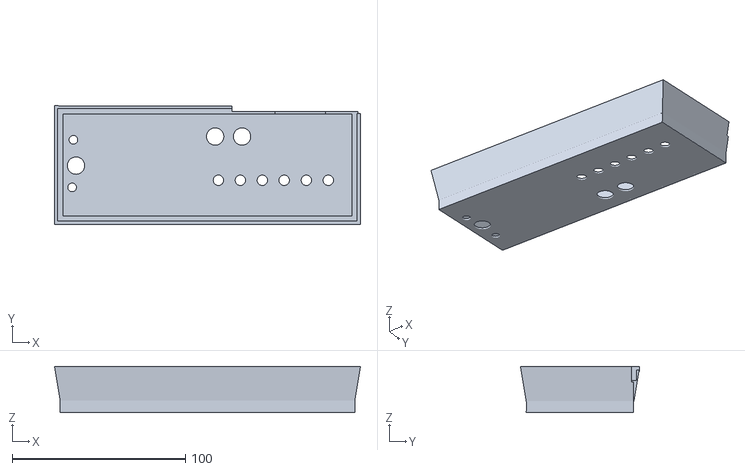
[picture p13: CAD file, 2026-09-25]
print files/STL Files/Body shell.stl.stl
176.8 x 68.9 x 26.8

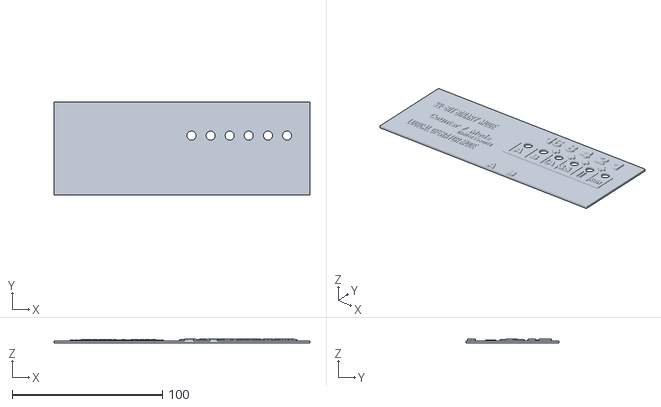
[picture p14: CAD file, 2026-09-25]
print files/STL Files/Top Plate.stl.stl
170.1 x 61.7 x 2.85

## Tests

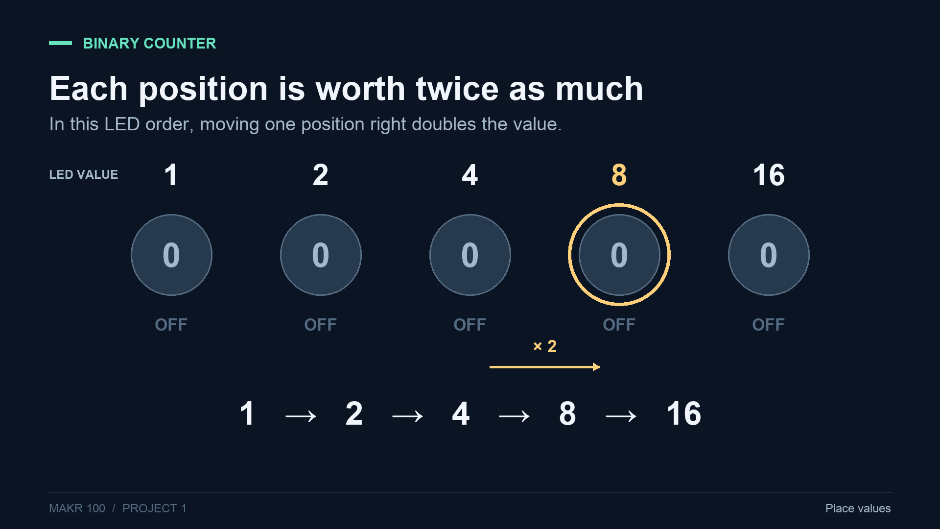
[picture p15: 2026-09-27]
Video/Exports/QA_Stills/02_weights.png

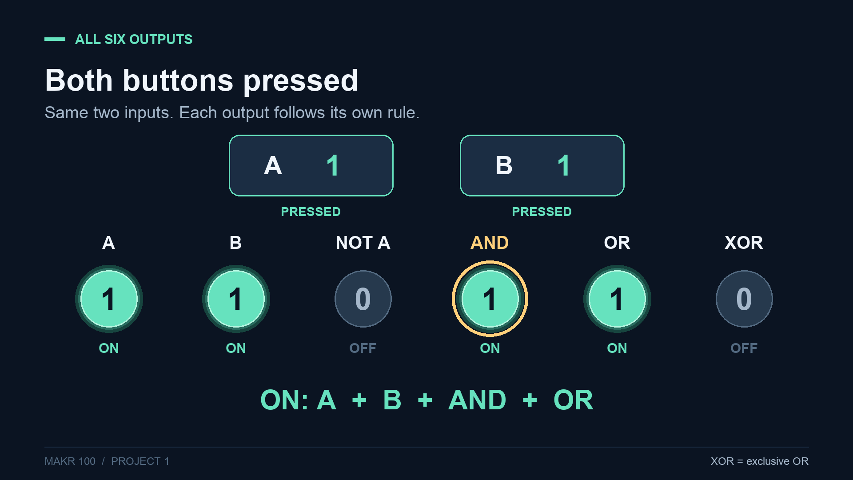
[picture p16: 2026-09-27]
Video/Exports/QA_Stills/20_both_pressed.png

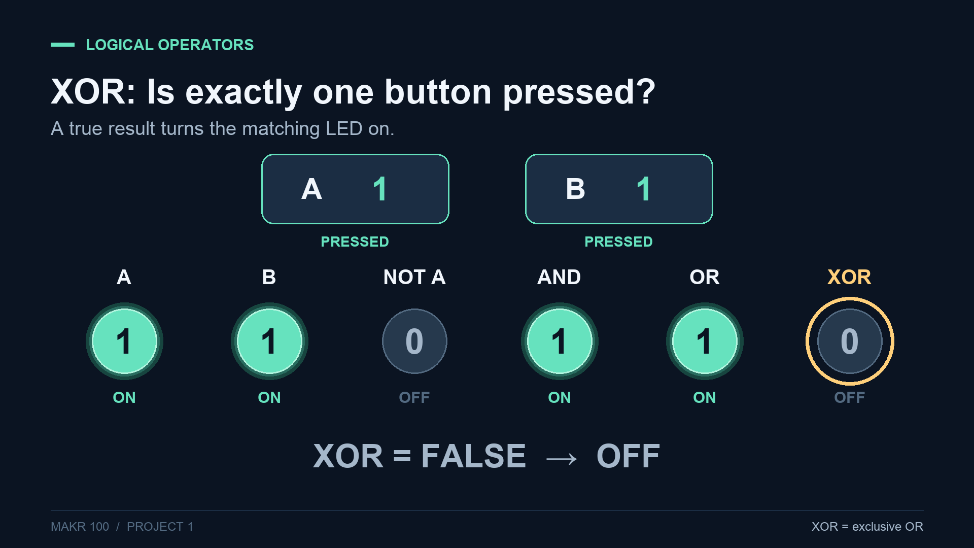
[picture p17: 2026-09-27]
Video/Exports/QA_Stills/22_xor_both_pressed.png

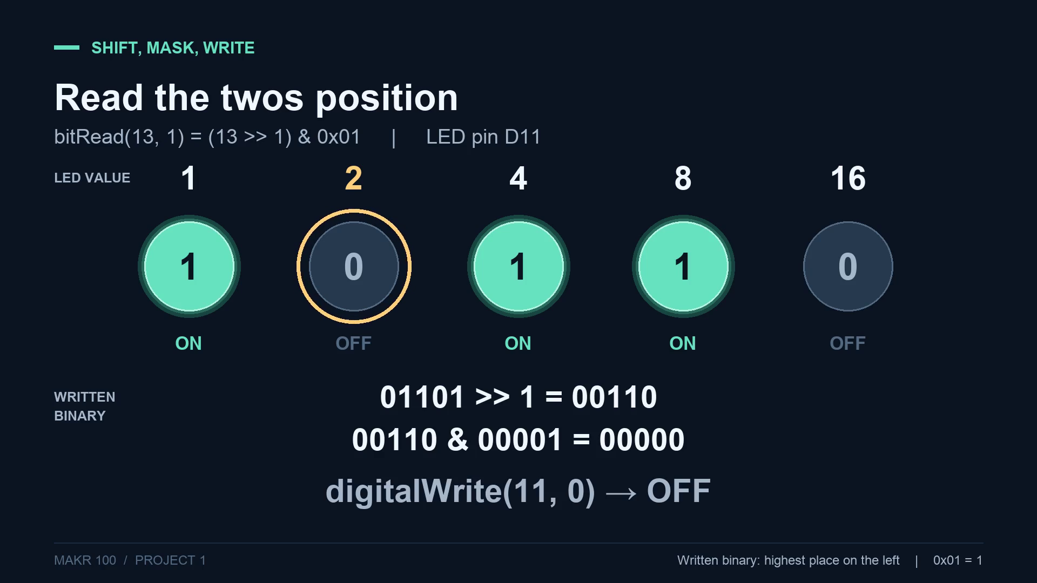
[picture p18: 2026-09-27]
Video/Exports/QA_Stills/24_finished_video_binary_math.png

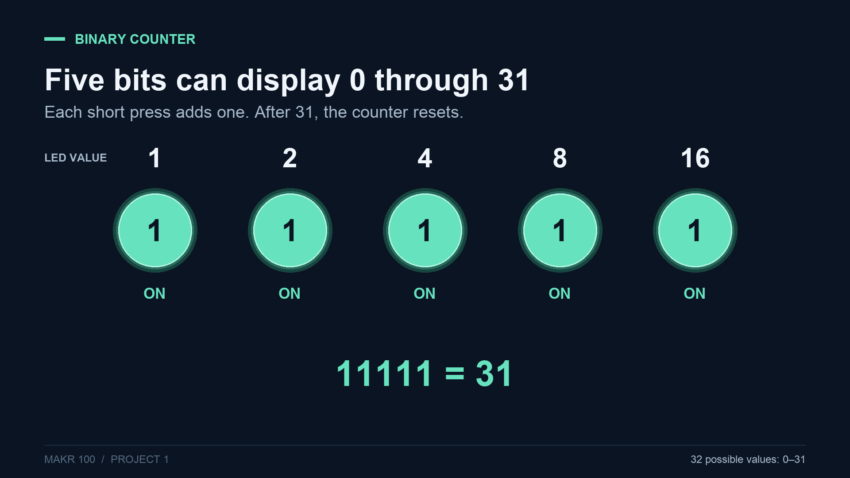
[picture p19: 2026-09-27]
Video/Exports/QA_Stills/11_rollover.png

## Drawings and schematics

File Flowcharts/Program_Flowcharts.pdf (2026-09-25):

MAKR 100 / PROJECT 1

# Main program flow

setup() runs once; loop() repeats continuously.

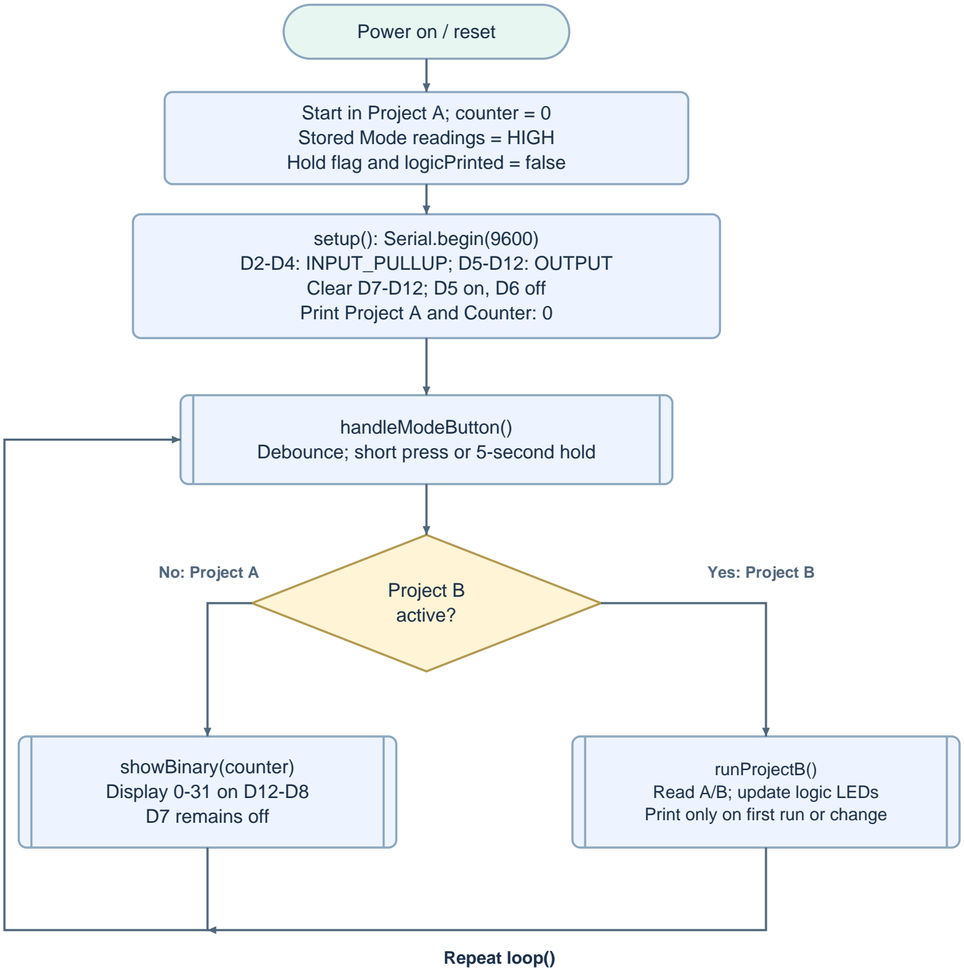
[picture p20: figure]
Power on / reset; Start in Project A; counter = 0 Stored Mode readings = HIGH Hold flag and logicPrinted = false; setup(): Serial.begin(9600) D2-D4: INPUT_PULLUP; D5-D12: OUTPUT Clear D7-D12; D5 on, D6 off Print Project A and Counter: 0; handleModeButton() Debounce; short press or 5-second hold; Project B active?; showBinary(counter) Display 0-31 on D12-D8 D7 remains off; runProjectB() Read A/B; update logic LEDs Print only on first run or change; No: Project A; Yes: Project B; Repeat loop()

Source: Program.ino | 1 / 4

Mode button: D2. Logic buttons A/B: D3/D4. LOW means pressed. Short Mode press increments on release in Project A.
Holding Mode for at least 5 seconds switches projects once per hold. The counter value is preserved when switching modes.

# Mode button handling

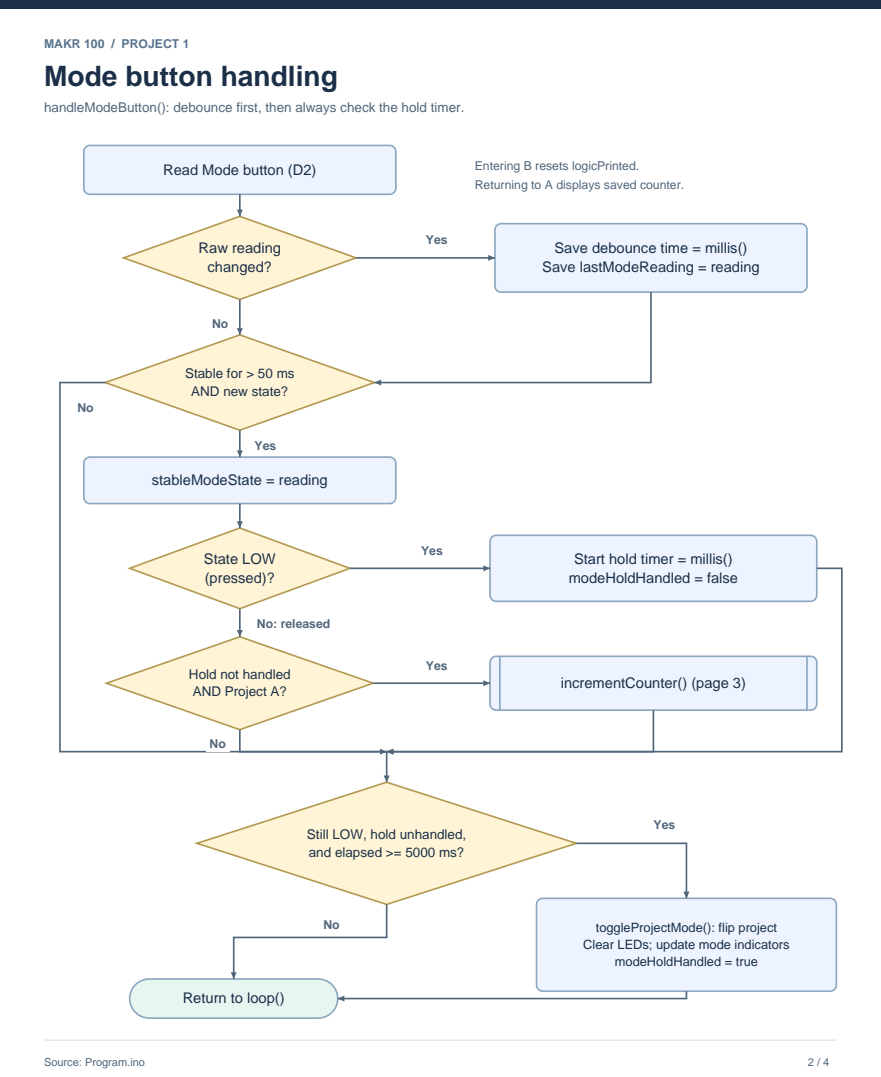
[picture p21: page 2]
Raw reading changed?; stableModeState = reading; State LOW (pressed)?; AND Project A?; incrementCounter() (page 3); Yes; No: released

handleModeButton(): debounce first, then always check the hold timer.

Read Mode button (D2)

Entering B resets logicPrinted.
Returning to A displays saved counter.

Save debounce time = millis()
Save lastModeReading = reading

Stable for > 50 ms
AND new state?

Start hold timer = millis()
modeHoldHandled = false

Hold not handled

Still LOW, hold unhandled,
and elapsed >= 5000 ms?

toggleProjectMode(): flip project
Clear LEDs; update mode indicators
modeHoldHandled = true

Return to loop()

# Project A: binary counter

incrementCounter() changes the value; showBinary(value) draws the five bits.

INCREMENT ON SHORT RELEASE | BINARY DISPLAY

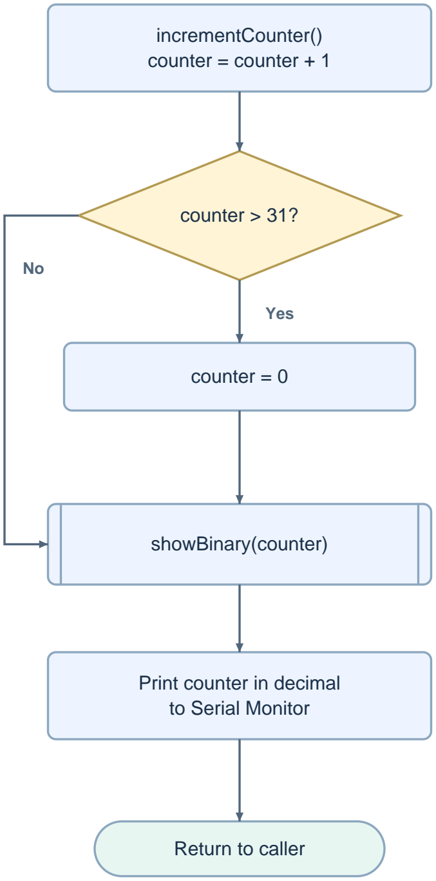
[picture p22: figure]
incrementCounter() counter = counter + 1; counter > 31?; counter = 0; showBinary(counter); Print counter in decimal to Serial Monitor; Return to caller; Yes

Binary pin order: D12 = 1, D11 = 2, D10 = 4, D9 = 8, D8 = 16.

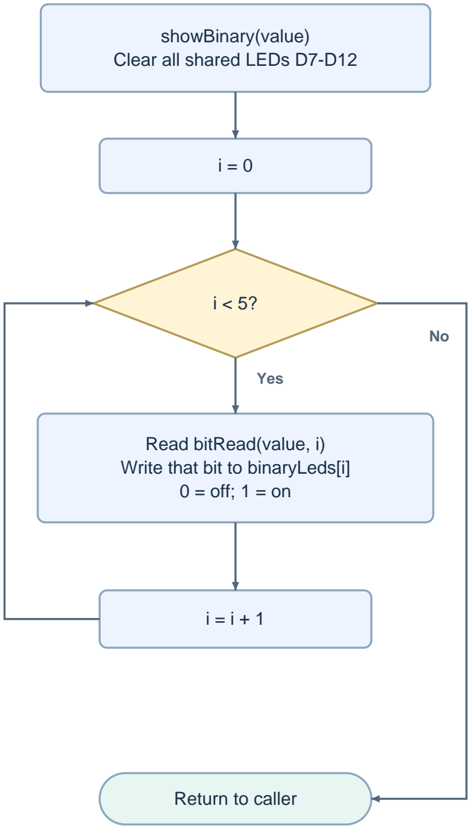
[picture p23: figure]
showBinary(value) Clear all shared LEDs D7-D12; Read bitRead(value, i) Write that bit to binaryLeds[i] 0 = off; 1 = on; Return to caller; Yes

D7 stays off in Project A. Five bits represent 32 values: 0 through 31. turnOffDataLeds() loops through all six shared pins and writes LOW.

# Project B: logical operators

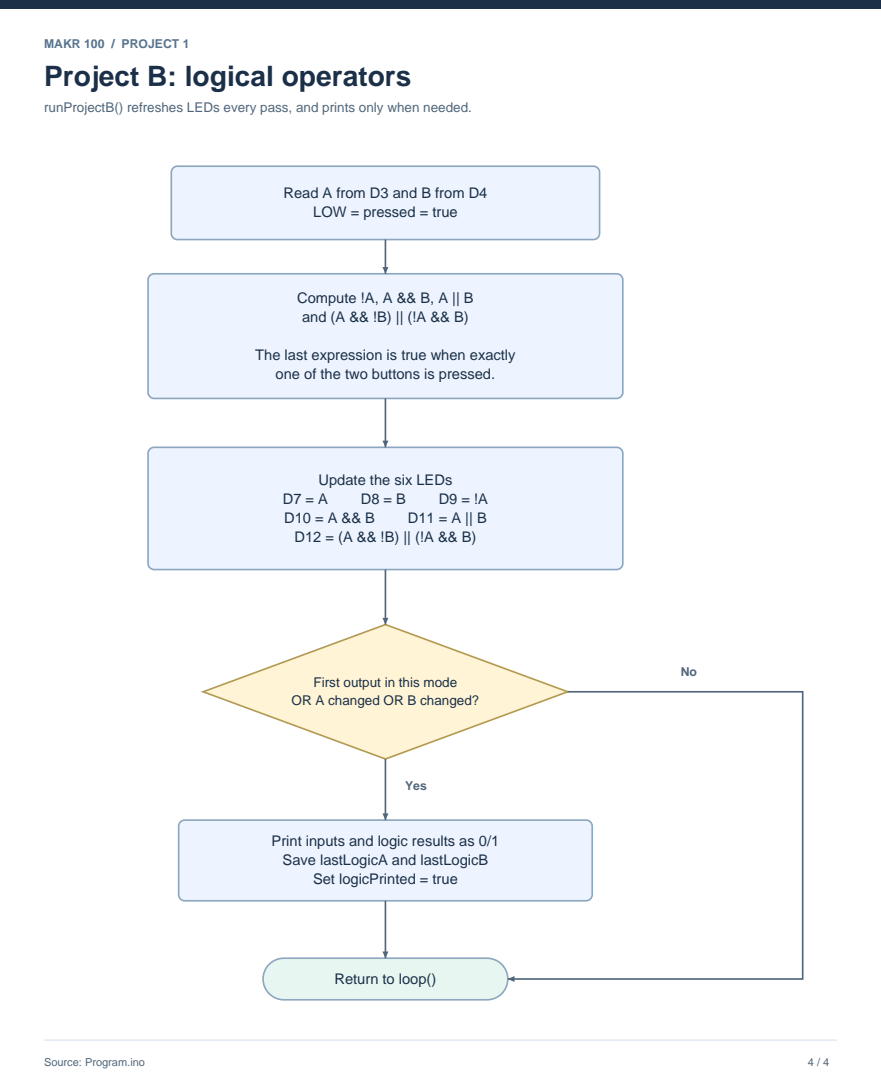
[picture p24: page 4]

runProjectB() refreshes LEDs every pass, and prints only when needed.

Read A from D3 and B from D4
LOW = pressed = true

The last expression is true when exactly
one of the two buttons is pressed.

Update the six LEDs

First output in this mode
OR A changed OR B changed?

Print inputs and logic results as 0/1
Save lastLogicA and lastLogicB
Set logicPrinted = true

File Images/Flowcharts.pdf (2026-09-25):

# Project 1 Flowcharts

# Arduino Program Architecture & Logic Breakdown (MAKR 100)

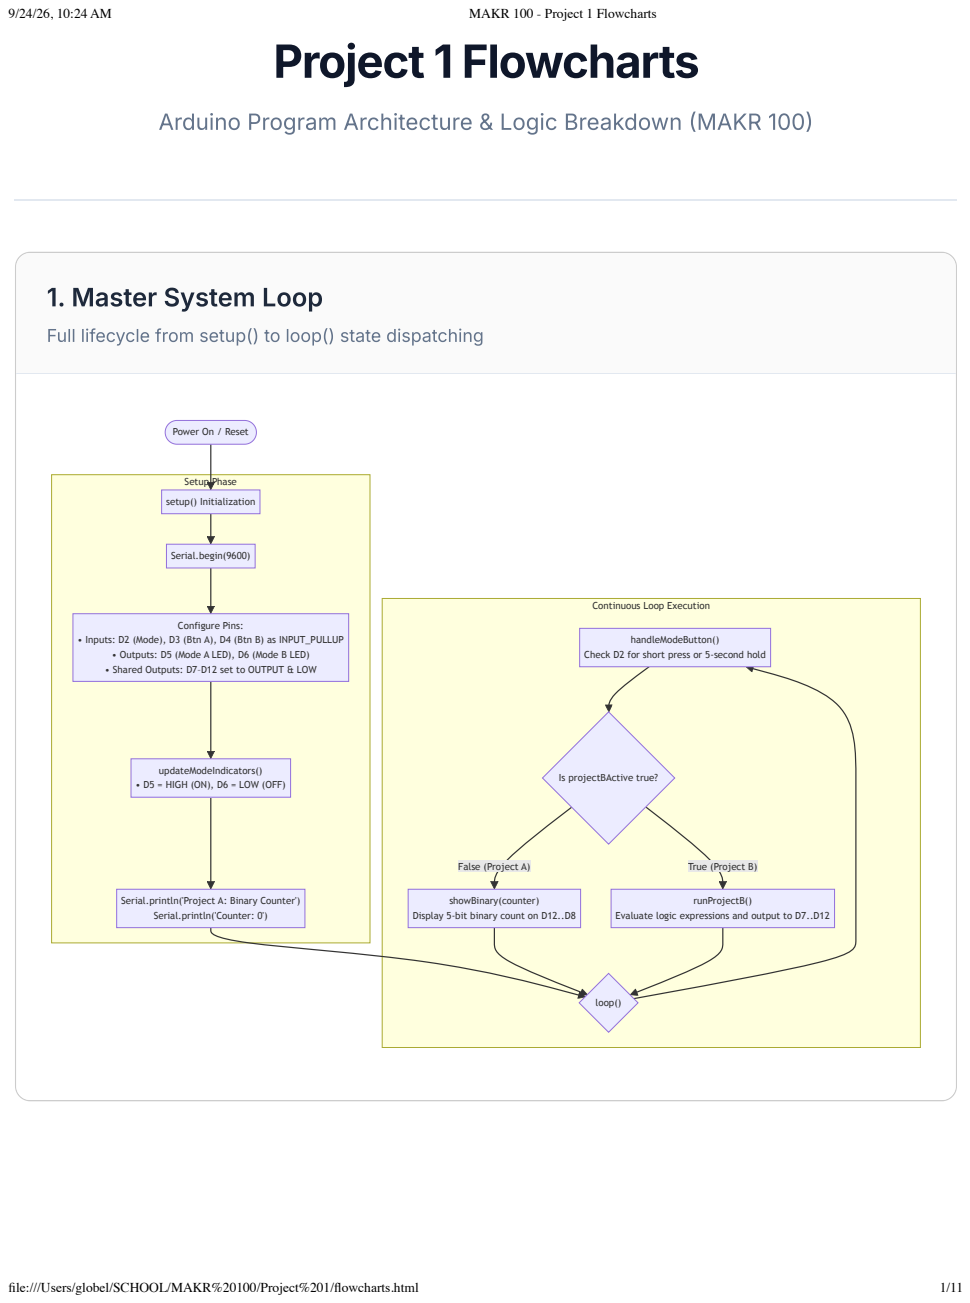
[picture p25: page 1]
Setup Phase; False (Project A); True (Project B); handleModeButton(); loop(); showBinary(counter); runProjectB(); Serial.begin(9600); setup() Initialization; Configure Pins:; MAKR 100 - Project 1 Flowcharts; file:///Users/globel/SCHOOL/MAKR%20100/Project%201/flowcharts.html

1. Master System Loop

Full lifecycle from setup() to loop() state dispatching

Power On / Reset

Continuous Loop Execution

• Inputs: D2 (Mode), D3 (Btn A), D4 (Btn B) as INPUT_PULLUP

• Outputs: D5 (Mode A LED), D6 (Mode B LED)
• Shared Outputs: D7–D12 set to OUTPUT & LOW

Check D2 for short press or 5-second hold

updateModeIndicators()
• D5 = HIGH (ON), D6 = LOW (OFF)

Is projectBActive true?

Serial.println('Project A: Binary Counter')
Serial.println('Counter: 0')

Display 5-bit binary count on D12..D8

Evaluate logic expressions and output to D7..D12

# 2. Mode Button & Hold/Press Handler

## 50ms software debounce, 5-second hold switch, and short-press counter increment

file:///Users/globel/SCHOOL/MAKR%20100/Project%201/flowcharts.html | 2/11

file:///Users/globel/SCHOOL/MAKR%20100/Project%201/flowcharts.html | 3/11

# handleModeButton()

# Read D2 (digitalRead)

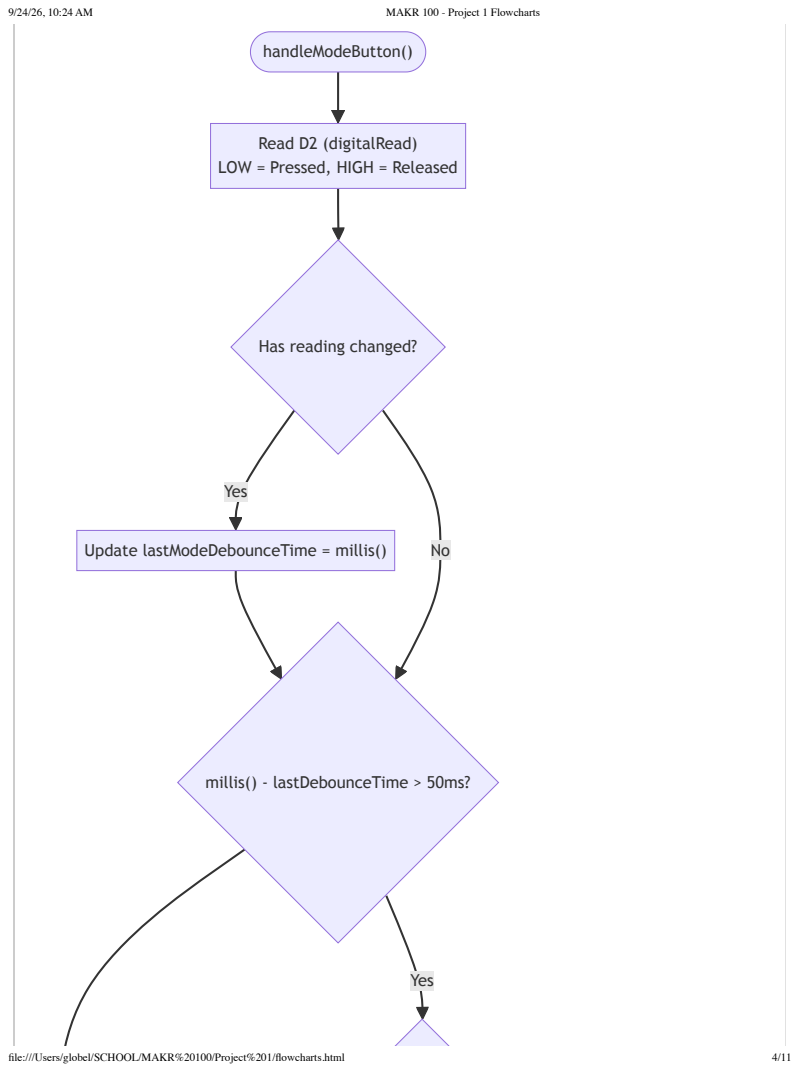
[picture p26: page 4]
Yes; millis() - lastDebounceTime > 50ms?; file:///Users/globel/SCHOOL/MAKR%20100/Project%201/flowcharts.html

LOW = Pressed, HIGH = Released

Has reading changed?

Update lastModeDebounceTime = millis()

# reading != stableModeState?

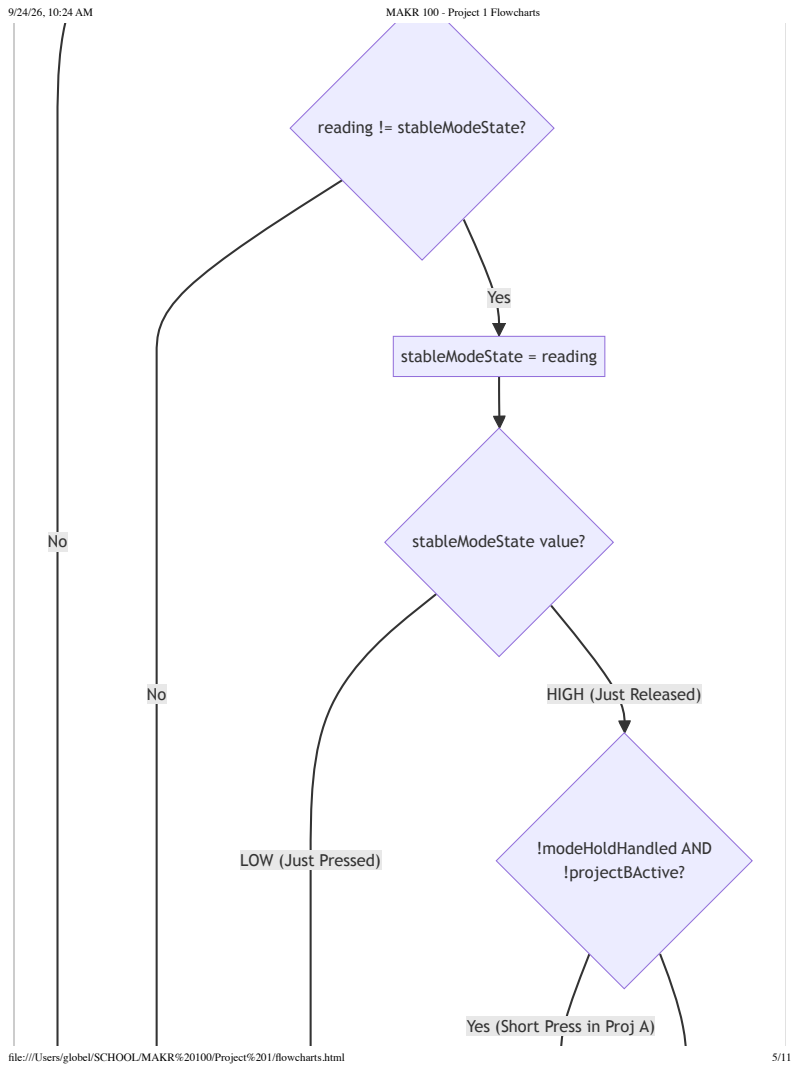
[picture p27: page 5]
Yes; stableModeState = reading; stableModeState value?; !modeHoldHandled AND !projectBActive?; file:///Users/globel/SCHOOL/MAKR%20100/Project%201/flowcharts.html

HIGH (Just Released)

LOW (Just Pressed)

Yes (Short Press in Proj A)

No

# modePressStartTime = millis()

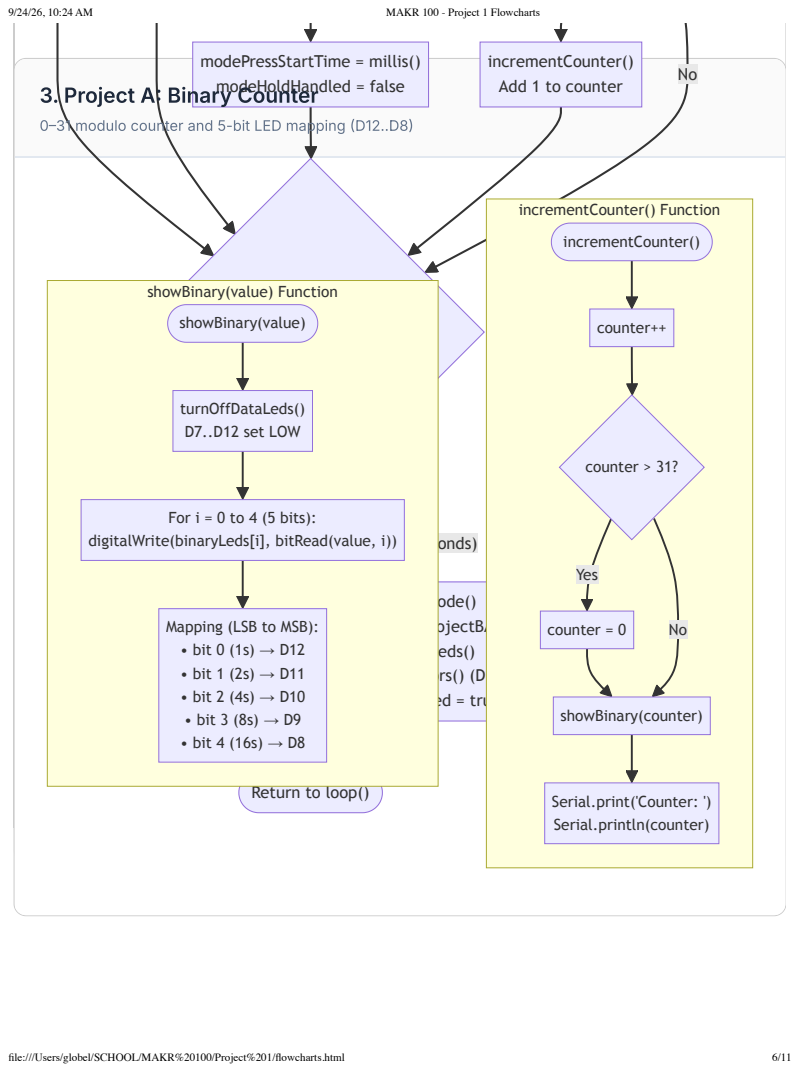
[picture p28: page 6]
modeHoldHandled = false; toggleProjectMode() • projectBActive = !projectBActive • turnOffDataLeds() • updateModeIndicators() (D5/D6) • modeHoldHandled = true; turnOffDataLeds() D7..D12 set LOW; Mapping (LSB to MSB): • bit 0 (1s) → D12 • bit 1 (2s) → D11 • bit 2 (4s) → D10 • bit 3 (8s) → D9 • bit 4 (16s) → D8; incrementCounter() Function; Yes; counter++; incrementCounter(); counter > 31?; counter = 0; showBinary(counter); file:///Users/globel/SCHOOL/MAKR%20100/Project%201/flowcharts.html

incrementCounter()
Add 1 to counter

3. Project A: Binary Counter

0–31 modulo counter and 5-bit LED mapping (D12..D8)

showBinary(value) Function
stableModeState == LOW AND
showBinary(value)
!modeHoldHandled AND
(millis() - pressTime) >= 5000ms?

For i = 0 to 4 (5 bits):

digitalWrite(binaryLeds[i], bitRead(value, i))

Yes (Held 5 Seconds)

Return to loop()

Serial.print('Counter: ')
Serial.println(counter)

# 4. Project B: Logic Gate Operators

## Read inputs A & B, evaluate Boolean gates, and drive outputs D7..D12

file:///Users/globel/SCHOOL/MAKR%20100/Project%201/flowcharts.html | 7/11

file:///Users/globel/SCHOOL/MAKR%20100/Project%201/flowcharts.html | 8/11

# runProjectB()

# Read Inputs (LOW = true):

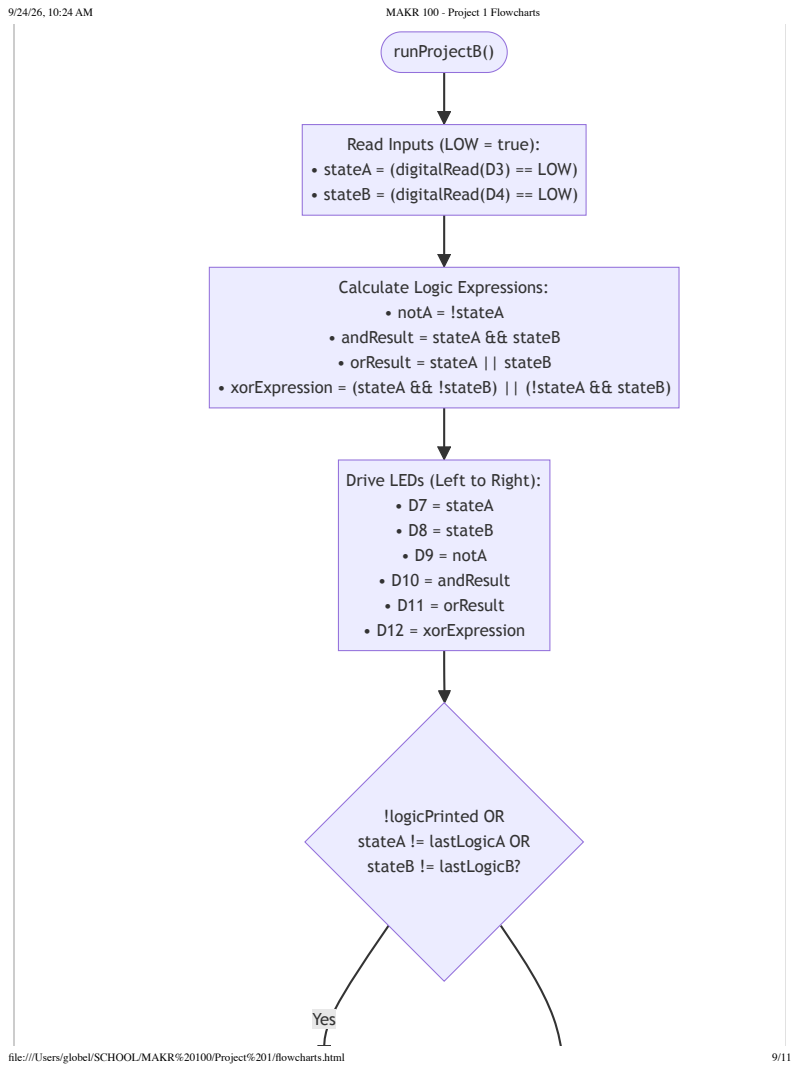
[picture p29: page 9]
Yes; file:///Users/globel/SCHOOL/MAKR%20100/Project%201/flowcharts.html

• stateA = (digitalRead(D3) == LOW)
• stateB = (digitalRead(D4) == LOW)

Calculate Logic Expressions:
• notA = !stateA
• andResult = stateA && stateB
• orResult = stateA || stateB

• xorExpression = (stateA && !stateB) || (!stateA && stateB)

Drive LEDs (Left to Right):
• D7 = stateA
• D8 = stateB
• D9 = notA
• D10 = andResult
• D11 = orResult
• D12 = xorExpression

!logicPrinted OR
stateA != lastLogicA OR
stateB != lastLogicB?

No

# printLogicStates(...)

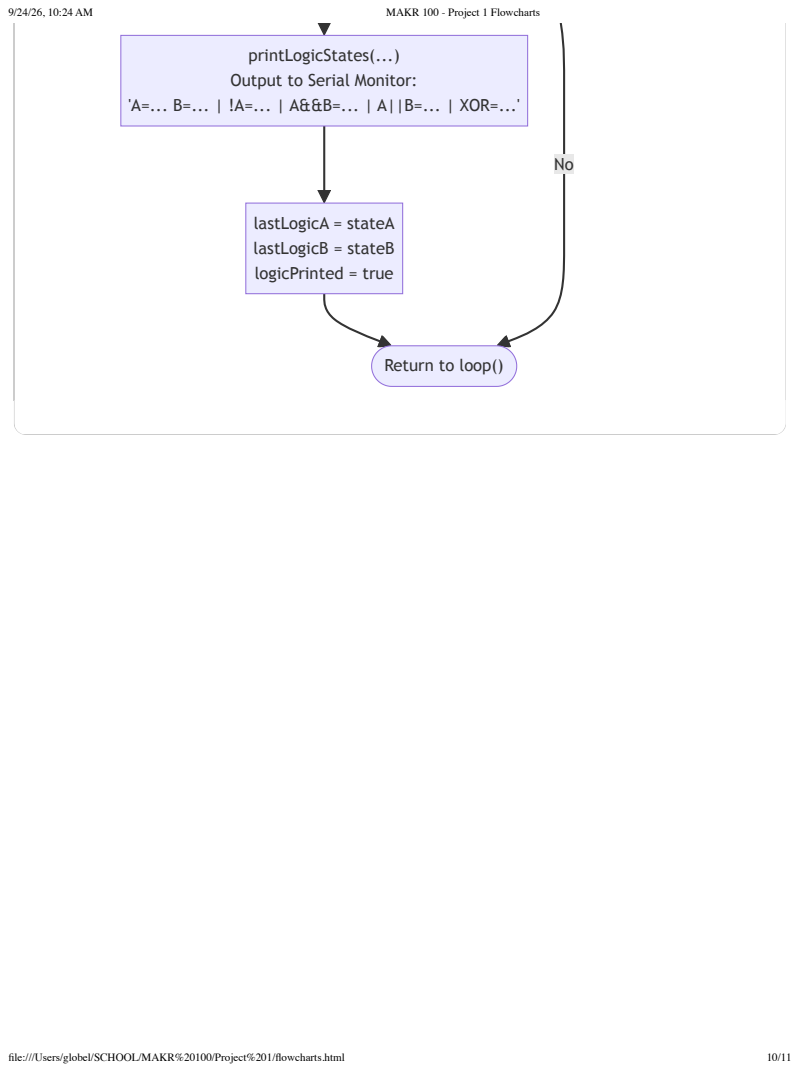
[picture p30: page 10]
'A=... B=... | !A=... | A&&B=... | A||B=... | XOR=...'; lastLogicA = stateA lastLogicB = stateB logicPrinted = true; file:///Users/globel/SCHOOL/MAKR%20100/Project%201/flowcharts.html

Output to Serial Monitor:

Return to loop()

# Hardware Pin Reference Map
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

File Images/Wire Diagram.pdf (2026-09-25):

A

1 | 2 | 3 | 4 | 5 | 6

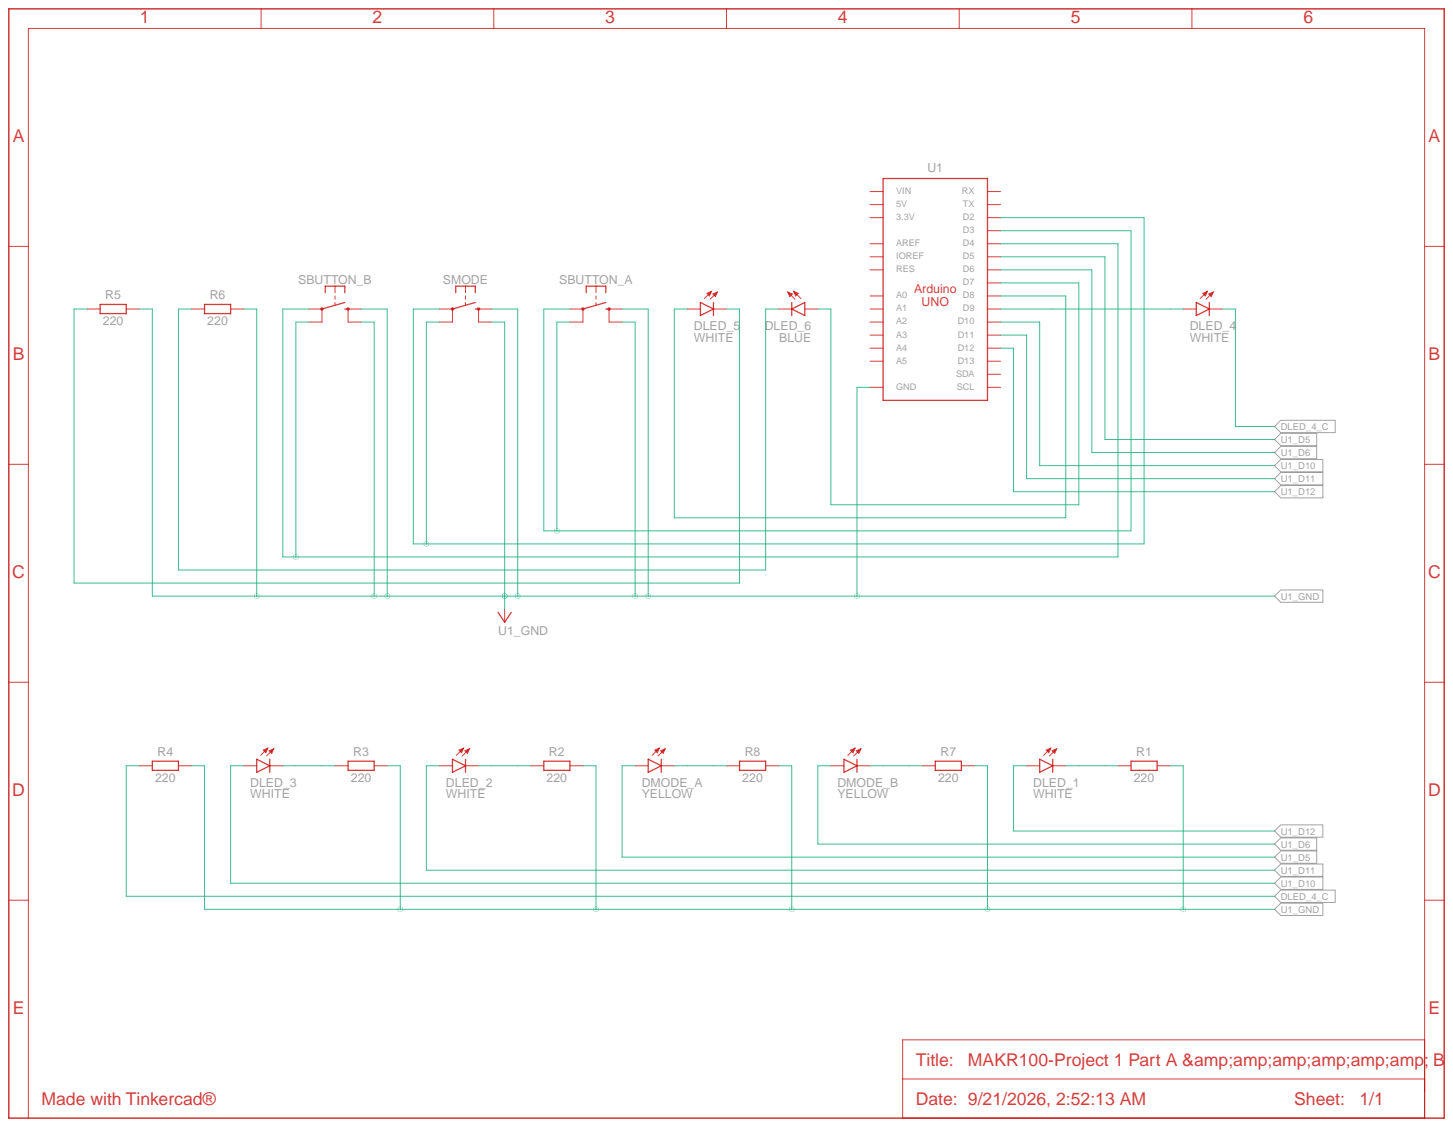
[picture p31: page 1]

Title: MAKR100-Project 1 Part A &amp;amp;amp;amp;amp;amp; B

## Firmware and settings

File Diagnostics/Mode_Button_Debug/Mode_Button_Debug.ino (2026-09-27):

/*
 ▄▄       ▄▄  ▄▄▄▄▄▄▄▄▄▄▄  ▄    ▄  ▄▄▄▄▄▄▄▄▄▄▄          ▄▄▄▄      ▄▄▄▄▄▄▄▄▄    ▄▄▄▄▄▄▄▄▄                                                                                           
▐░░▌     ▐░░▌▐░░░░░░░░░░░▌▐░▌  ▐░▌▐░░░░░░░░░░░▌       ▄█░░░░▌    ▐░░░░░░░░░▌  ▐░░░░░░░░░▌                                                                                          
▐░▌░▌   ▐░▐░▌▐░█▀▀▀▀▀▀▀█░▌▐░▌ ▐░▌ ▐░█▀▀▀▀▀▀▀█░▌      ▐░░▌▐░░▌   ▐░█░█▀▀▀▀▀█░▌▐░█░█▀▀▀▀▀█░▌                                                                                         
▐░▌▐░▌ ▐░▌▐░▌▐░▌       ▐░▌▐░▌▐░▌  ▐░▌       ▐░▌       ▀▀ ▐░░▌   ▐░▌▐░▌    ▐░▌▐░▌▐░▌    ▐░▌                                                                                         
▐░▌ ▐░▐░▌ ▐░▌▐░█▄▄▄▄▄▄▄█░▌▐░▌░▌   ▐░█▄▄▄▄▄▄▄█░▌          ▐░░▌   ▐░▌ ▐░▌   ▐░▌▐░▌ ▐░▌   ▐░▌                                                                                         
▐░▌  ▐░▌  ▐░▌▐░░░░░░░░░░░▌▐░░▌    ▐░░░░░░░░░░░▌          ▐░░▌   ▐░▌  ▐░▌  ▐░▌▐░▌  ▐░▌  ▐░▌                                                                                         
▐░▌   ▀   ▐░▌▐░█▀▀▀▀▀▀▀█░▌▐░▌░▌   ▐░█▀▀▀▀█░█▀▀           ▐░░▌   ▐░▌   ▐░▌ ▐░▌▐░▌   ▐░▌ ▐░▌                                                                                         
▐░▌       ▐░▌▐░▌       ▐░▌▐░▌▐░▌  ▐░▌     ▐░▌            ▐░░▌   ▐░▌    ▐░▌▐░▌▐░▌    ▐░▌▐░▌                                                                                         
▐░▌       ▐░▌▐░▌       ▐░▌▐░▌ ▐░▌ ▐░▌      ▐░▌       ▄▄▄▄█░░█▄▄▄▐░█▄▄▄▄▄█░█░▌▐░█▄▄▄▄▄█░█░▌                                                                                         
▐░▌       ▐░▌▐░▌       ▐░▌▐░▌  ▐░▌▐░▌       ▐░▌     ▐░░░░░░░░░░░▌▐░░░░░░░░░▌  ▐░░░░░░░░░▌                                                                                          
 ▀         ▀  ▀         ▀  ▀    ▀  ▀         ▀       ▀▀▀▀▀▀▀▀▀▀▀  ▀▀▀▀▀▀▀▀▀    ▀▀▀▀▀▀▀▀▀                                                                                           
                                                                                                                                                                                   
 ▄▄▄▄▄▄▄▄▄▄▄  ▄▄▄▄▄▄▄▄▄▄▄  ▄▄▄▄▄▄▄▄▄▄▄  ▄▄▄▄▄▄▄▄▄▄▄  ▄▄▄▄▄▄▄▄▄▄▄  ▄▄▄▄▄▄▄▄▄▄▄  ▄▄▄▄▄▄▄▄▄▄▄              ▄         ▄     ▄▄▄▄                                                       
▐░░░░░░░░░░░▌▐░░░░░░░░░░░▌▐░░░░░░░░░░░▌▐░░░░░░░░░░░▌▐░░░░░░░░░░░▌▐░░░░░░░░░░░▌▐░░░░░░░░░░░▌            ▐░▌       ▐░▌  ▄█░░░░▌                                                      
▐░█▀▀▀▀▀▀▀█░▌▐░█▀▀▀▀▀▀▀█░▌▐░█▀▀▀▀▀▀▀█░▌ ▀▀▀▀▀█░█▀▀▀ ▐░█▀▀▀▀▀▀▀▀▀ ▐░█▀▀▀▀▀▀▀▀▀  ▀▀▀▀█░█▀▀▀▀            ▄█░█▄▄▄▄▄▄▄█░█▄▐░░▌▐░░▌                                                      
▐░▌       ▐░▌▐░▌       ▐░▌▐░▌       ▐░▌      ▐░▌    ▐░▌          ▐░▌               ▐░▌               ▐░░░░░░░░░░░░░░░▌▀▀ ▐░░▌                                                      
▐░█▄▄▄▄▄▄▄█░▌▐░█▄▄▄▄▄▄▄█░▌▐░▌       ▐░▌      ▐░▌    ▐░█▄▄▄▄▄▄▄▄▄ ▐░▌               ▐░▌                ▀█░█▀▀▀▀▀▀▀█░█▀    ▐░░▌                                                      
▐░░░░░░░░░░░▌▐░░░░░░░░░░░▌▐░▌       ▐░▌      ▐░▌    ▐░░░░░░░░░░░▌▐░▌               ▐░▌                 ▐░▌       ▐░▌     ▐░░▌                                                      
▐░█▀▀▀▀▀▀▀▀▀ ▐░█▀▀▀▀█░█▀▀ ▐░▌       ▐░▌      ▐░▌    ▐░█▀▀▀▀▀▀▀▀▀ ▐░▌               ▐░▌                ▄█░█▄▄▄▄▄▄▄█░█▄    ▐░░▌                                                      
▐░▌          ▐░▌     ▐░▌  ▐░▌       ▐░▌      ▐░▌    ▐░▌          ▐░▌               ▐░▌               ▐░░░░░░░░░░░░░░░▌   ▐░░▌                                                      
▐░▌          ▐░▌      ▐░▌ ▐░█▄▄▄▄▄▄▄█░▌ ▄▄▄▄▄█░▌    ▐░█▄▄▄▄▄▄▄▄▄ ▐░█▄▄▄▄▄▄▄▄▄      ▐░▌                ▀█░█▀▀▀▀▀▀▀█░█▀▄▄▄▄█░░█▄▄▄                                                   
▐░▌          ▐░▌       ▐░▌▐░░░░░░░░░░░▌▐░░░░░░░▌    ▐░░░░░░░░░░░▌▐░░░░░░░░░░░▌     ▐░▌                 ▐░▌       ▐░▌▐░░░░░░░░░░░▌                                                  
 ▀            ▀         ▀  ▀▀▀▀▀▀▀▀▀▀▀  ▀▀▀▀▀▀▀      ▀▀▀▀▀▀▀▀▀▀▀  ▀▀▀▀▀▀▀▀▀▀▀       ▀                   ▀         ▀  ▀▀▀▀▀▀▀▀▀▀▀                                                   
                                                                                                                                                                                   
 ▄▄▄▄▄▄▄▄▄▄   ▄         ▄       ▄         ▄  ▄▄▄▄▄▄▄▄▄▄▄  ▄▄▄▄▄▄▄▄▄▄▄  ▄▄▄▄▄▄▄▄▄▄▄  ▄         ▄       ▄▄▄▄▄▄▄▄▄▄   ▄▄▄▄▄▄▄▄▄▄▄  ▄▄▄▄▄▄▄▄▄▄▄  ▄▄▄▄▄▄▄▄▄▄▄  ▄▄▄▄▄▄▄▄▄▄▄  ▄▄▄▄▄▄▄▄▄▄▄ 
▐░░░░░░░░░░▌ ▐░▌       ▐░▌     ▐░▌       ▐░▌▐░░░░░░░░░░░▌▐░░░░░░░░░░░▌▐░░░░░░░░░░░▌▐░▌       ▐░▌     ▐░░░░░░░░░░▌ ▐░░░░░░░░░░░▌▐░░░░░░░░░░░▌▐░░░░░░░░░░░▌▐░░░░░░░░░░░▌▐░░░░░░░░░░░▌
▐░█▀▀▀▀▀▀▀█░▌▐░▌       ▐░▌     ▐░▌       ▐░▌▐░█▀▀▀▀▀▀▀█░▌▐░█▀▀▀▀▀▀▀█░▌▐░█▀▀▀▀▀▀▀█░▌▐░▌       ▐░▌     ▐░█▀▀▀▀▀▀▀█░▌▐░█▀▀▀▀▀▀▀█░▌▐░█▀▀▀▀▀▀▀█░▌ ▀▀▀▀█░█▀▀▀▀ ▐░█▀▀▀▀▀▀▀█░▌▐░█▀▀▀▀▀▀▀▀▀ 
▐░▌       ▐░▌▐░▌       ▐░▌     ▐░▌       ▐░▌▐░▌       ▐░▌▐░▌       ▐░▌▐░▌       ▐░▌▐░▌       ▐░▌     ▐░▌       ▐░▌▐░▌       ▐░▌▐░▌       ▐░▌     ▐░▌     ▐░▌       ▐░▌▐░▌          
▐░█▄▄▄▄▄▄▄█░▌▐░█▄▄▄▄▄▄▄█░▌     ▐░█▄▄▄▄▄▄▄█░▌▐░█▄▄▄▄▄▄▄█░▌▐░█▄▄▄▄▄▄▄█░▌▐░█▄▄▄▄▄▄▄█░▌▐░█▄▄▄▄▄▄▄█░▌     ▐░█▄▄▄▄▄▄▄█░▌▐░█▄▄▄▄▄▄▄█░▌▐░█▄▄▄▄▄▄▄█░▌     ▐░▌     ▐░▌       ▐░▌▐░█▄▄▄▄▄▄▄▄▄ 
▐░░░░░░░░░░▌ ▐░░░░░░░░░░░▌     ▐░░░░░░░░░░░▌▐░░░░░░░░░░░▌▐░░░░░░░░░░░▌▐░░░░░░░░░░░▌▐░░░░░░░░░░░▌     ▐░░░░░░░░░░▌ ▐░░░░░░░░░░░▌▐░░░░░░░░░░░▌     ▐░▌     ▐░▌       ▐░▌▐░░░░░░░░░░░▌
▐░█▀▀▀▀▀▀▀█░▌ ▀▀▀▀█░█▀▀▀▀      ▐░█▀▀▀▀▀▀▀█░▌▐░█▀▀▀▀▀▀▀█░▌▐░█▀▀▀▀█░█▀▀ ▐░█▀▀▀▀█░█▀▀  ▀▀▀▀█░█▀▀▀▀      ▐░█▀▀▀▀▀▀▀█░▌▐░█▀▀▀▀▀▀▀█░▌▐░█▀▀▀▀█░█▀▀      ▐░▌     ▐░▌       ▐░▌ ▀▀▀▀▀▀▀▀▀█░▌
▐░▌       ▐░▌     ▐░▌          ▐░▌       ▐░▌▐░▌       ▐░▌▐░▌     ▐░▌  ▐░▌     ▐░▌       ▐░▌          ▐░▌       ▐░▌▐░▌       ▐░▌▐░▌     ▐░▌       ▐░▌     ▐░▌       ▐░▌          ▐░▌
▐░█▄▄▄▄▄▄▄█░▌     ▐░▌          ▐░▌       ▐░▌▐░▌       ▐░▌▐░▌      ▐░▌ ▐░▌      ▐░▌      ▐░▌          ▐░█▄▄▄▄▄▄▄█░▌▐░▌       ▐░▌▐░▌      ▐░▌      ▐░▌     ▐░█▄▄▄▄▄▄▄█░▌ ▄▄▄▄▄▄▄▄▄█░▌
▐░░░░░░░░░░▌      ▐░▌          ▐░▌       ▐░▌▐░▌       ▐░▌▐░▌       ▐░▌▐░▌       ▐░▌     ▐░▌          ▐░░░░░░░░░░▌ ▐░▌       ▐░▌▐░▌       ▐░▌     ▐░▌     ▐░░░░░░░░░░░▌▐░░░░░░░░░░░▌
 ▀▀▀▀▀▀▀▀▀▀        ▀            ▀         ▀  ▀         ▀  ▀         ▀  ▀         ▀       ▀            ▀▀▀▀▀▀▀▀▀▀   ▀         ▀  ▀         ▀       ▀       ▀▀▀▀▀▀▀▀▀▀▀  ▀▀▀▀▀▀▀▀▀▀▀ 
                                                                                                                                                                                   
Two Projects On One Arduino

  Project A: Binary counter from 0 to 31 or 32 Bits
  Hold counter button for 5 seconds to switch
  Project B: Logical operators using Button A and Button B.
 
  Pin map (D for Digital Pins)               
  D2  = Counter / Mode 
  D3  = Button A 
  D4  = Button B
  D5  = Project A indicator LED
  D6  = Project B indicator LED
  D7-D12 = Shared Output LEDs


  In english we read left to right but Binary reads from right to left. So Its
  to note the LED numbering will be from the top down High to low However the 
  Logical Operator statements read like normal language, so Project B will  read left to right.


 I need to define all the pins as const global values becuase they wont be changing and most 
 will be used for 2 diffrent purposes. Other wise I would have labeled them one,two,four,eight,
 sixteen and A,B,notA,aAndB,aOrB,xOr (exclusive or) Also becuase their GLOBAL constansts they are 
 cIn ALL_CAPS_WITH_UNDERSCORES

*/


// ==================================================================================================================================
// ========================================================== Global Constant =======================================================
// ==================================================================================================================================

// -------------------- BUTTON PINS --------------------
// The buttons are wired to GND and use INPUT_PULLUP.
// Not pressed = HIGH. Pressed = LOW.
const int MODE_BUTTON_PIN = 2;
const int BUTTON_A_PIN = 3;
const int BUTTON_B_PIN = 4;
// -------------------- MODE INDICATOR LEDS --------------------
// D5 turns on for Project A.
// D6 turns on for Project B.
const int MODE_A_LED_PIN = 5;
const int MODE_B_LED_PIN = 6;
// -------------------- PROJECT A LED ORDER (using an Array) --------------------
// Binary uses right-to-left bit order.
// evean though they are global arrays becuase they are at the top 
// outside the function and are const I felt it makes sense more for the array not to be all capps
// DATA LED1 = D12 = 1s bit.
// DATA LED2 = D11 = 2s bit.
// DATA LED3 = D10 = 4s bit.
// DATA LED4 = D9  = 8s bit.
// DATA LED5 = D8  = 16s bit.
const int binaryLeds[] = {12, 11, 10, 9, 8};
const int BINARY_LED_COUNT = 5;
// -------------------- PROJECT B LED ORDER ARRAY--------------------
// Logic reads left-to-right on the breadboard.
// D7  = A indicator
// D8  = B indicator
// D9  = !A
// D10 = A && B
// D11 = A || B
// D12 = (A && !B) || (!A && B)
const int logicLeds[] = {7, 8, 9, 10, 11, 12};
const int LOGIC_LED_COUNT = 6;
// -------------------- ALL SHARED OUTPUT LEDS --------------------
// This list is used only to clear every shared LED before changing displays.
const int allDataLeds[] = {12, 11, 10, 9, 8, 7};
const int DATA_LED_COUNT = 6;
// -------------------- TIMING SETTINGS --------------------
// Hold the Mode button for 5 seconds to switch projects.
const unsigned long MODE_HOLD_TIME = 5000;

// Debounce keeps one physical button press from being read as many presses.
const unsigned long DEBOUNCE_DELAY = 50;

// -------------------- PROGRAM STATE --------------------
// false means Project A is active. true means Project B is active.
bool projectBActive = false;

// Project A counter value. It goes from 0 to 31, then resets to 0.
int counter = 0;

// -------------------- MODE BUTTON TRACKING --------------------
// These variables help tell the difference between a short press and a 5 second hold.
int lastModeReading = HIGH;
int stableModeState = HIGH;
unsigned long lastModeDebounceTime = 0;
unsigned long modePressStartTime = 0;
bool modeHoldHandled = false;

// Diagnostic-only state; the original control logic is unchanged.
unsigned long debugModeRawChanges = 0;
unsigned long debugLastReportTime = 0;

// -------------------- SERIAL MONITOR TRACKING --------------------
// These variables keep Project B from printing the same line over and over.
bool lastLogicA = false;
bool lastLogicB = false;
bool logicPrinted = false;

void setup() {
  // Start the Serial Monitor at 9600 baud.
  // This lets us display the counter number and the logic results.
  Serial.begin(9600);
  Serial.println("MODE_DIAG_20260926_V3");

  // INPUT_PULLUP is the reason pressed buttons read LOW instead  of HIGH.
  pinMode(MODE_BUTTON_PIN, INPUT_PULLUP);
  pinMode(BUTTON_A_PIN, INPUT_PULLUP);
  pinMode(BUTTON_B_PIN, INPUT_PULLUP);

  // Set the two mode LEDs as outputs.
  pinMode(MODE_A_LED_PIN, OUTPUT);
  pinMode(MODE_B_LED_PIN, OUTPUT);

  // We use a loop to configure all the shared LEDs at once. It starts at i = 0 and 
  // runs until it hits DATA_LED_COUNT, setting each pin in the array to OUTPUT and 
  // turning it off so we have a clean slate. (this is in the void setup loop still)
  for (int i = 0; i < DATA_LED_COUNT; i++) {
    pinMode(allDataLeds[i], OUTPUT);
    digitalWrite(allDataLeds[i], LOW);
  }

  // Start in Project A.
  // This turns on D5 and turns off D6.
  updateModeIndicators();

  // Show the starting project and starting value in the Serial Monitor.
  Serial.println("Project A: Binary Counter");
  Serial.println("Counter: 0");
}

void loop() {
  // The Mode button always needs to be checked first.
  // Notice this is our only loop. its super short becuase it has to catch buttin pushes                                                                                                                                                                                                                                                                                                                                                                                                                                                                                                   
  // A short press counts in Project A.
  // A 5 second hold switches between Project A and Project B.
  handleModeDebugCommand();
  handleModeButton();

  // Run the act ive project. sence the z
  if (projectBActive) {
    runProjectB();
  } else {
    showBinary(counter);
  }

  printModeDebug();
}

void handleModeButton() {
  // Read the Mode button.
  // HIGH = not pressed. LOW = pressed.
  int reading = digitalRead(MODE_BUTTON_PIN);

  // If the reading changed, save the time.
  // The code waits briefly before trusting the change.
  if (reading != lastModeReading) {
    debugModeRawChanges++;
    lastModeDebounceTime = millis();
    lastModeReading = reading;
  }

  // Debounce check:
  // Only accept the new button state after it has stayed stable long enough.
  if ((millis() - lastModeDebounceTime) > DEBOUNCE_DELAY) {
    if (reading != stableModeState) {
      stableModeState = reading;
      Serial.println(stableModeState == LOW ? "DBG press" : "DBG release");

      if (stableModeState == LOW) {
        // The Mode button was just pressed.
        // Start timing in case this becomes a 5 second hold.
        modePressStartTime = millis();
        modeHoldHandled = false;
      } else {
        // The Mode button was just released.
        // If the hold did not already switch modes, treat this as a short press.
        if (!modeHoldHandled && !projectBActive) {
          incrementCounter();
        }
      }
    }
  }

  // Long-hold check:
  // If the button is still held after 5 seconds, switch projects.
  if (stableModeState == LOW && !modeHoldHandled) {
    if ((millis() - modePressStartTime) >= MODE_HOLD_TIME) {
      toggleProjectMode();

      // This prevents the same hold from switching back and forth repeatedly.
      modeHoldHandled = true;
    }
  }
}

void toggleProjectMode() {
  // Flip the active project.
  // false becomes true, true becomes false.
  projectBActive = !projectBActive;

  // Clear old LEDs so Project A output does not stay on during Project B,
  // and Project B output does not stay on during Project A.
  turnOffDataLeds();

  // Update D5 and D6 mode indicator LEDs.
  updateModeIndicators();

  if (projectBActive) {
    // We just entered Project B.
    // Let Project B print its first line again.
    logicPrinted = false;

    // Print labels for the logic project.
    Serial.println("Project B: Logical Operators");
    Serial.println("Left to right: A, B, !A, A&&B, A||B, (A&&!B)||(!A&&B)");
  } else {
    // We just returned to Project A.
    Serial.println("Project A: Binary Counter");
    showBinary(counter);
  }
}

void updateModeIndicators() {
  // D5 and D6 show which project is active.
  // Project A: D5 on, D6 off.
  // Project B: D5 off, D6 on.
  digitalWrite(MODE_A_LED_PIN, projectBActive ? LOW : HIGH);
  digitalWrite(MODE_B_LED_PIN, projectBActive ? HIGH : LOW);
}
;;;;
void incrementCounter() {
  // Add 1 to the Project A counter.
  counter++;

  // Project A only counts from 0 to 31.
  // After 31, the next press resets it back to 0.
  if (counter > 31) {
    counter = 0;
  }

  // Update the binary LEDs to match the new number.
  showBinary(counter);

  // Also print the decimal number to the Serial Monitor.
  Serial.print("Counter: ");
  Serial.println(counter);
}

void showBinary(int value) {
  // Turn off all shared LEDs first.
  // This makes sure old 1 bits turn off when they become 0 bits.
  turnOffDataLeds();

  // bitRead(value, i) pulls one binary digit out of the number.
  // i = 0 reads the 1s bit.
  // i = 1 reads the 2s bit.
  // i = 2 reads the 4s bit.
  // i = 3 reads the 8s bit.
  // i = 4 reads the 16s bit.                                                                                                                                                                                                                                                                                                                                                                                                                                                                                                                                                                                                                                                                       
  for (int i = 0; i < BINARY_LED_COUNT; i++) {
    digitalWrite(binaryLeds[i], bitRead(value, i));
  }
}

void runProjectB() {
  // Read Button A and Button B.
  // Since the buttons use INPUT_PULLUP, LOW means pressed.
  bool stateA = (digitalRead(BUTTON_A_PIN) == LOW);
  bool stateB = (digitalRead(BUTTON_B_PIN) == LOW);

  // !A means NOT A.
  // This is true when Button A is NOT pressed.
  bool notA = !stateA;

  // A && B means A AND B.
  // This is true only when both buttons are pressed at the same time.
  bool andResult = stateA && stateB;

  // A || B means A OR B.
  // This is true when A is pressed, B is pressed, or both are pressed.
  bool orResult = stateA || stateB;

  // (A && !B) || (!A && B) means only one button is pressed.
  // This is often called XOR, but the assignment asks for the full expression,
  // so the comments and Serial Monitor show the full expression.
  bool xorExpression = (stateA && !stateB) || (!stateA && stateB);

  // Project B LED order fix:
  // The logic LEDs use logicLeds[], not binaryLeds[].
  // This makes the lights match the written logic order from left to right.
  digitalWrite(logicLeds[0], stateA);         // D7  shows A.
  digitalWrite(logicLeds[1], stateB);         // D8  shows B.
  digitalWrite(logicLeds[2], notA);           // D9  shows !A.
  digitalWrite(logicLeds[3], andResult);      // D10 shows A && B.
  digitalWrite(logicLeds[4], orResult);       // D11 shows A || B.
  digitalWrite(logicLeds[5], xorExpression);  // D12 shows (A&&!B)||(!A&&B).

  // Only print when A or B changes.
  // Without this, the Serial Monitor would fill up nonstop.
  if (!logicPrinted || stateA != lastLogicA || stateB != lastLogicB) {
    printLogicStates(stateA, stateB, notA, andResult, orResult, xorExpression);

    // Save the last values so we can detect the next change.
    lastLogicA = stateA;
    lastLogicB = stateB;
    logicPrinted = true;
  }
}

void printLogicStates(bool stateA, bool stateB, bool notA, bool andResult, bool orResult, bool xorExpression) {
  // This function prints one clean Serial Monitor line for Project B.
  // Each value is printed as 1 for true/on and 0 for false/off.

  // Print the two button input values first.
  Serial.print("A=");
  Serial.print(stateA ? 1 : 0);

  Serial.print(" B=");
  Serial.print(stateB ? 1 : 0);

  // Print the required logic outputs in the same order as the LEDs.
  Serial.print(" | !A=");
  Serial.print(notA ? 1 : 0);

  Serial.print(" | A&&B=");
  Serial.print(andResult ? 1 : 0);

  Serial.print(" | A||B=");
  Serial.print(orResult ? 1 : 0);

  Serial.print(" | (A&&!B)||(!A&&B)=");
  Serial.println(xorExpression ? 1 : 0);
}

void turnOffDataLeds() {
  // Turn off every shared Project LED from D12 down to D7.
  // This is used before drawing binary and before changing modes.
  for (int i = 0; i < DATA_LED_COUNT; i++) {
    digitalWrite(allDataLeds[i], LOW);
  }
}

// One compact report per second, plus accepted press/release messages above.
// raw/stable: 0 = pressed, 1 = released. handled: 1 = this hold already switched.
// held: milliseconds since the accepted press. edges: raw changes since last report.
void printModeDebug() {
  unsigned long now = millis();
  if (now - debugLastReportTime < 1000) return;
  debugLastReportTime = now;
  Serial.print("DBG ");
  Serial.print(projectBActive ? "B" : "A");
  Serial.print(" raw=");
  Serial.print(digitalRead(MODE_BUTTON_PIN));
  Serial.print(" stable=");
  Serial.print(stableModeState);
  Serial.print(" handled=");
  Serial.print(modeHoldHandled ? 1 : 0);
  Serial.print(" held=");
  Serial.print(stableModeState == LOW ? now - modePressStartTime : 0);
  Serial.print(" edges=");
  Serial.println(debugModeRawChanges);
  debugModeRawChanges = 0;
}

// Diagnostic commands: force A or B without operating the physical button.
// All pin assignments and the original button/mode logic remain unchanged.
void handleModeDebugCommand() {
  if (Serial.available() == 0) return;
  char command = Serial.read();
  if (command == 'a' || command == 'A') {
    Serial.println("DBG command: A");
    if (projectBActive) toggleProjectMode();
  } else if (command == 'b' || command == 'B') {
    Serial.println("DBG command: B");
    if (!projectBActive) toggleProjectMode();
  } else if (command == 't' || command == 'T') {
    probeModeOutputCoupling();
  }
}
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

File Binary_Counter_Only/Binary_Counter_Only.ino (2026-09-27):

// Harry Bartos - MAKR 100 Project 1, Option A
// Press and release the button to count from 0 through 31, then back to 0.
// Button: D2 to GND. LEDs: D12=1, D11=2, D10=4, D9=8, D8=16.

#include <Arduino.h>

const int BUTTON_PIN = 2;
const int LED_PINS[] = {12, 11, 10, 9, 8};
const int LED_COUNT = 5;

int counter = 0;
int lastButtonState = HIGH;  // INPUT_PULLUP: released = HIGH, pressed = LOW.

void displayCount();

void setup() {
  Serial.begin(9600);
  pinMode(BUTTON_PIN, INPUT_PULLUP);

  for (int i = 0; i < LED_COUNT; i++) {
    pinMode(LED_PINS[i], OUTPUT);
  }

  displayCount();  // Start at zero with all five LEDs off.
}

void loop() {
  int buttonState = digitalRead(BUTTON_PIN);

  if (buttonState != lastButtonState) {
    delay(50);  // Ignore a brief bounce in the button contacts.
    buttonState = digitalRead(BUTTON_PIN);

    if (buttonState != lastButtonState) {
      lastButtonState = buttonState;

      if (buttonState == HIGH) {  
        counter++;

        if (counter > 31) {
          counter = 0;
        }

        displayCount();
      }
    }
  }
}

void displayCount() {
  for (int i = 0; i < LED_COUNT; i++) {
    digitalWrite(LED_PINS[i], bitRead(counter, i));
  }

  Serial.print("Counter: ");
  Serial.println(counter);
}
